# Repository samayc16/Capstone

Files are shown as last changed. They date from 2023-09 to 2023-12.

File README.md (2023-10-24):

# Code Documentation for Full STEAM Ahead
### Samay Chandna
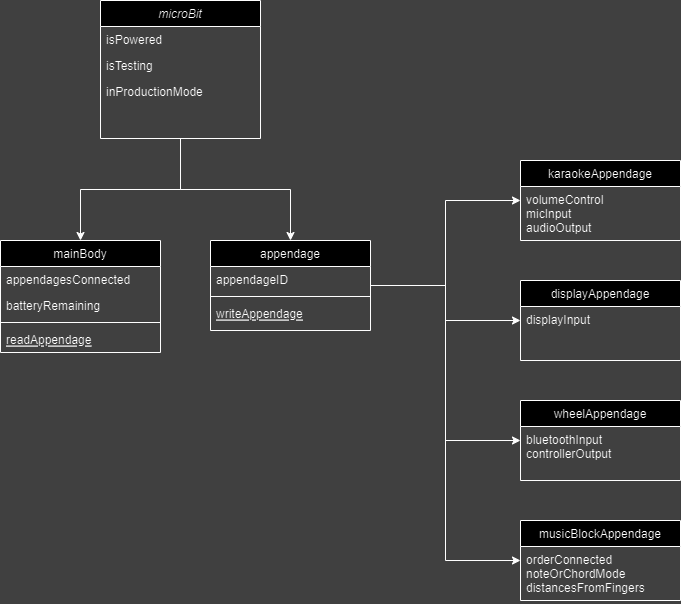
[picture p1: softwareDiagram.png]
OOP Software Diagram

#### Useful Links
* [micro:bit API for TS](https://makecode.microbit.org/reference)
* [micro:bit Pinout](https://makecode.microbit.org/device/pins)
* [micro:bit Progress with Simulator](https://makecode.microbit.org/_6Y6azqKkKF0U)

#### Progress Made so far
* 26/09/2023
  * [Have skeleton working in block code](https://makecode.microbit.org/_6Y6azqKkKF0U)
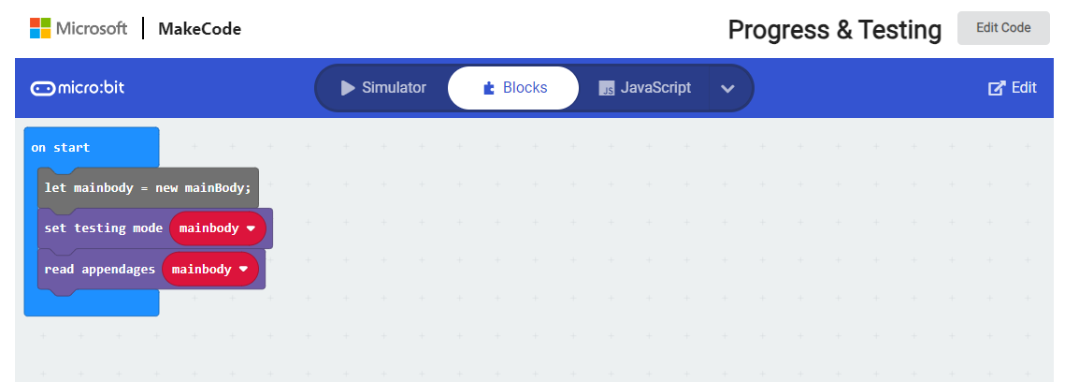
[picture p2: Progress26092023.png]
Today's Progress
  * 
* 28/09/2023
  * [Moved from naive implementation to I2C](https://makecode.microbit.org/S04872-52139-73553-07116)
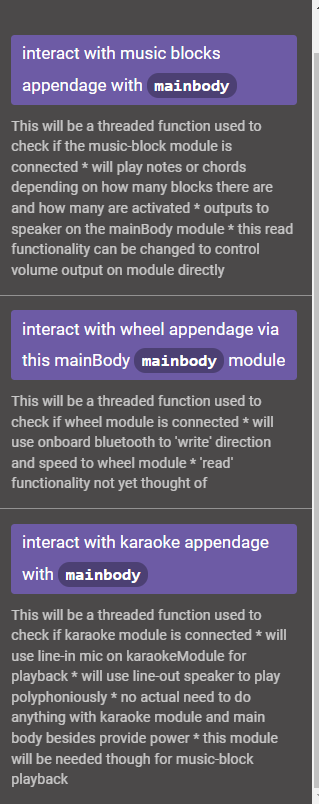
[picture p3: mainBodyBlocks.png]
Real block code with descriptions
  * 
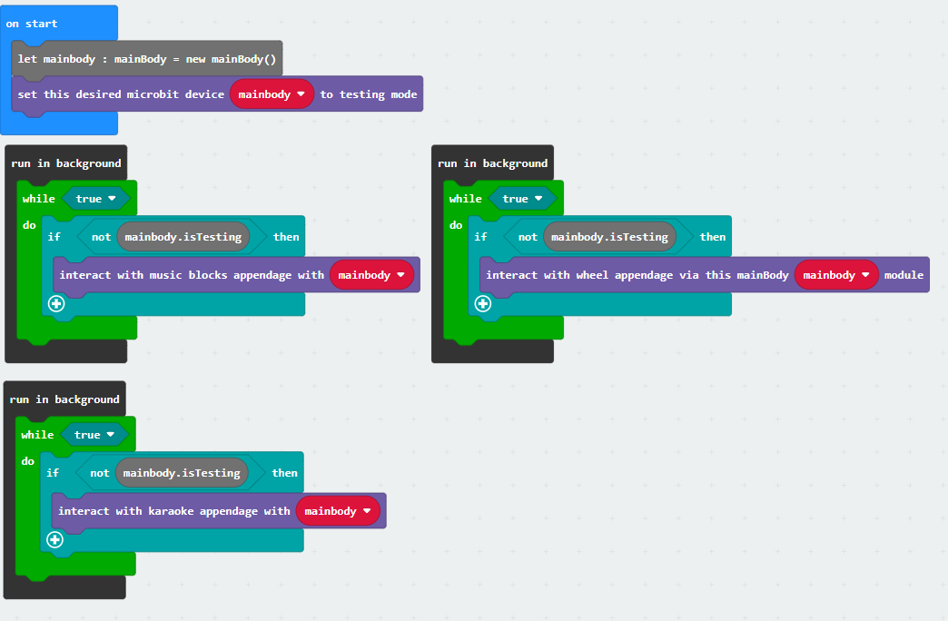
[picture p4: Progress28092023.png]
Today's Progress
  * 
* 24/10/2023
  * Little bit of absence due to midterms, break, and interviews
  * Great progress made, all the block code looks production-ready
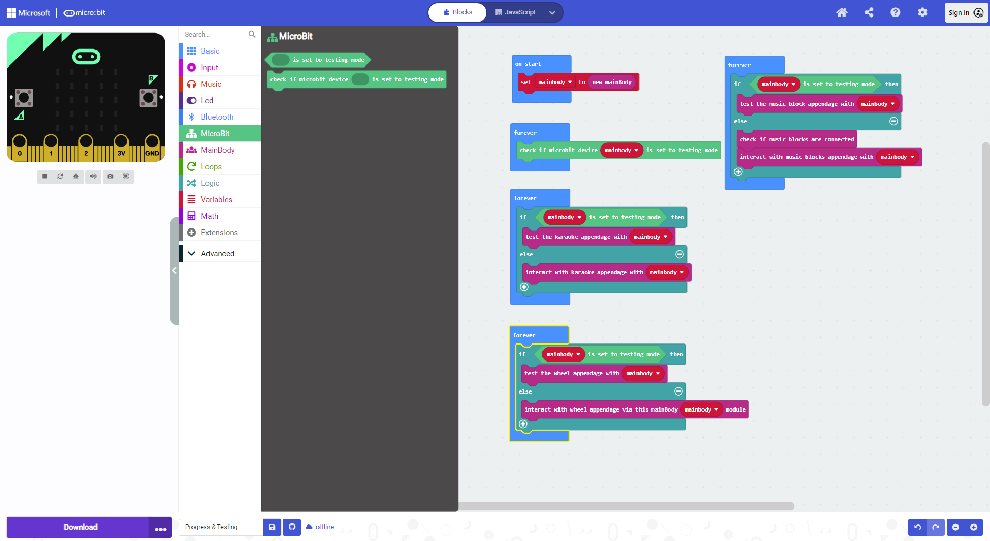
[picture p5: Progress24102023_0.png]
  * 
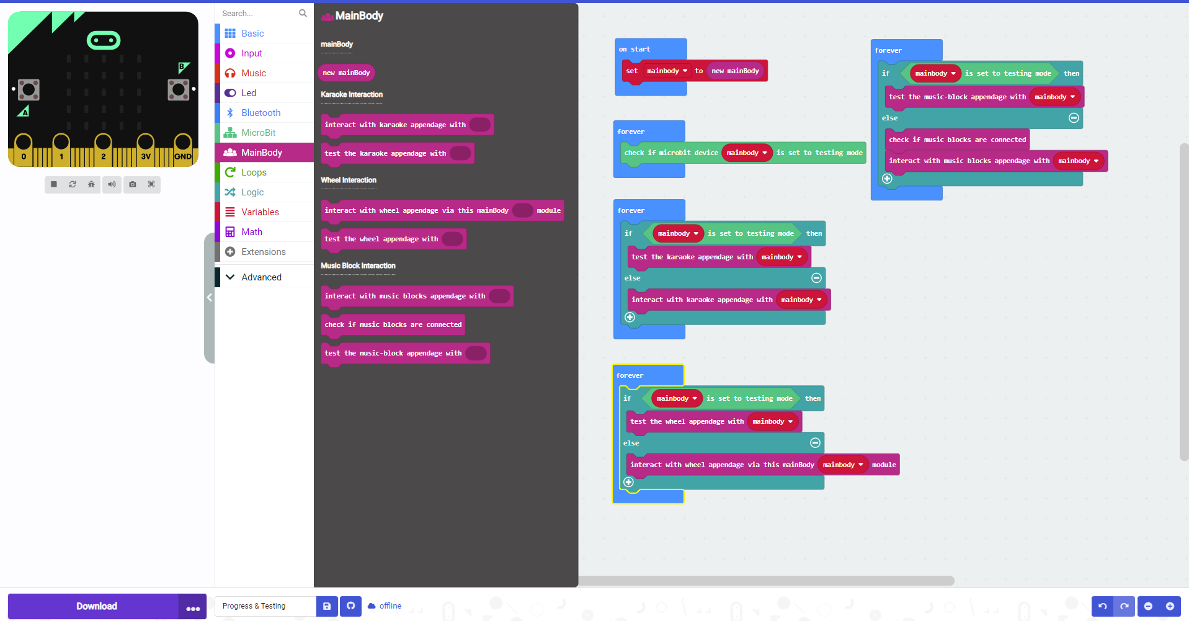
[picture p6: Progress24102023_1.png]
  * 
  * Deleted all deprecated python code
  * Deleted all TS files that are not being used
  * Got rid of custom.ts, made seperate modules for each (makes MUCH more sense)
  * Added PCB to github repo
  * Added my parts of CDR document and presentation

#### Helpful Notes
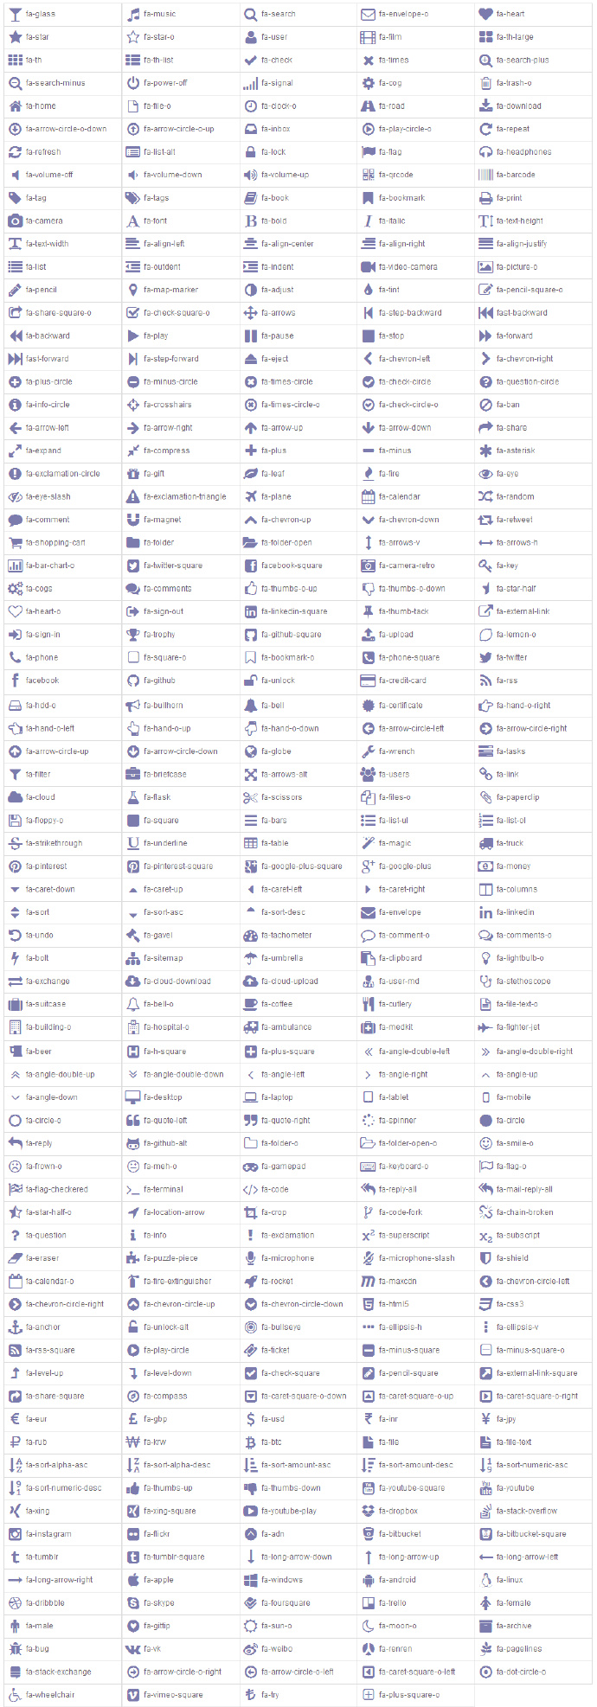
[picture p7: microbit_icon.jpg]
icons for microbit modules


*"\uf000", "id": "fa-glass"

*"\uf001", "id": "fa-music"

*"\uf002", "id": "fa-search"

*"\uf003", "id": "fa-envelope-o"

*"\uf004", "id": "fa-heart"

*"\uf005", "id": "fa-star"

*"\uf006", "id": "fa-star-o"

*"\uf007", "id": "fa-user"

*"\uf008", "id": "fa-film"

*"\uf009", "id": "fa-th-large"

*"\uf00a", "id": "fa-th"

*"\uf00b", "id": "fa-th-list"

*"\uf00c", "id": "fa-check"

*"\uf00d", "id": "fa-times"

*"\uf00e", "id": "fa-search-plus"

*"\uf010", "id": "fa-search-minus"

*"\uf011", "id": "fa-power-off"

*"\uf012", "id": "fa-signal"

*"\uf013", "id": "fa-cog"

*"\uf014", "id": "fa-trash-o"

*"\uf015", "id": "fa-home"

*"\uf016", "id": "fa-file-o"

*"\uf017", "id": "fa-clock-o"

*"\uf018", "id": "fa-road"

*"\uf019", "id": "fa-download"

*"\uf01a", "id": "fa-arrow-circle-o-down"

*"\uf01b", "id": "fa-arrow-circle-o-up"

*"\uf01c", "id": "fa-inbox"

*"\uf01d", "id": "fa-play-circle-o"

*"\uf01e", "id": "fa-repeat"

*"\uf021", "id": "fa-refresh"

*"\uf022", "id": "fa-list-alt"

*"\uf023", "id": "fa-lock"

*"\uf024", "id": "fa-flag"

*"\uf025", "id": "fa-headphones"

*"\uf026", "id": "fa-volume-off"

*"\uf027", "id": "fa-volume-down"

*"\uf028", "id": "fa-volume-up"

*"\uf029", "id": "fa-qrcode"

*"\uf02a", "id": "fa-barcode"

*"\uf02b", "id": "fa-tag"

*"\uf02c", "id": "fa-tags"

*"\uf02d", "id": "fa-book"

*"\uf02e", "id": "fa-bookmark"

*"\uf02f", "id": "fa-print"

*"\uf030", "id": "fa-camera"

*"\uf031", "id": "fa-font"

*"\uf032", "id": "fa-bold"

*"\uf033", "id": "fa-italic"

*"\uf034", "id": "fa-text-height"

*"\uf035", "id": "fa-text-width"

*"\uf036", "id": "fa-align-left"

*"\uf037", "id": "fa-align-center"

*"\uf038", "id": "fa-align-right"

*"\uf039", "id": "fa-align-justify"

*"\uf03a", "id": "fa-list"

*"\uf03b", "id": "fa-outdent"

*"\uf03c", "id": "fa-indent"

*"\uf03d", "id": "fa-video-camera"

*"\uf03e", "id": "fa-picture-o"

*"\uf040", "id": "fa-pencil"

*"\uf041", "id": "fa-map-marker"

*"\uf042", "id": "fa-adjust"

*"\uf043", "id": "fa-tint"

*"\uf044", "id": "fa-pencil-square-o"

*"\uf045", "id": "fa-share-square-o"

*"\uf046", "id": "fa-check-square-o"

*"\uf047", "id": "fa-arrows"

*"\uf048", "id": "fa-step-backward"

*"\uf049", "id": "fa-fast-backward"

*"\uf04a", "id": "fa-backward"

*"\uf04b", "id": "fa-play"

*"\uf04c", "id": "fa-pause"

*"\uf04d", "id": "fa-stop"

*"\uf04e", "id": "fa-forward"

*"\uf050", "id": "fa-fast-forward"

*"\uf051", "id": "fa-step-forward"

*"\uf052", "id": "fa-eject"

*"\uf053", "id": "fa-chevron-left"

*"\uf054", "id": "fa-chevron-right"

*"\uf055", "id": "fa-plus-circle"

*"\uf056", "id": "fa-minus-circle"

*"\uf057", "id": "fa-times-circle"

*"\uf058", "id": "fa-check-circle"

*"\uf059", "id": "fa-question-circle"

*"\uf05a", "id": "fa-info-circle"

*"\uf05b", "id": "fa-crosshairs"

*"\uf05c", "id": "fa-times-circle-o"

*"\uf05d", "id": "fa-check-circle-o"

*"\uf05e", "id": "fa-ban"

*"\uf060", "id": "fa-arrow-left"

*"\uf061", "id": "fa-arrow-right"

*"\uf062", "id": "fa-arrow-up"

*"\uf063", "id": "fa-arrow-down"

*"\uf064", "id": "fa-share"

*"\uf065", "id": "fa-expand"

*"\uf066", "id": "fa-compress"

*"\uf067", "id": "fa-plus"

*"\uf068", "id": "fa-minus"

*"\uf069", "id": "fa-asterisk"

*"\uf06a", "id": "fa-exclamation-circle"

*"\uf06b", "id": "fa-gift"

*"\uf06c", "id": "fa-leaf"

*"\uf06d", "id": "fa-fire"

*"\uf06e", "id": "fa-eye"

*"\uf070", "id": "fa-eye-slash"

*"\uf071", "id": "fa-exclamation-triangle"

*"\uf072", "id": "fa-plane"

*"\uf073", "id": "fa-calendar"

*"\uf074", "id": "fa-random"

*"\uf075", "id": "fa-comment"

*"\uf076", "id": "fa-magnet"

*"\uf077", "id": "fa-chevron-up"

*"\uf078", "id": "fa-chevron-down"

*"\uf079", "id": "fa-retweet"

*"\uf07a", "id": "fa-shopping-cart"

*"\uf07b", "id": "fa-folder"

*"\uf07c", "id": "fa-folder-open"

*"\uf07d", "id": "fa-arrows-v"

*"\uf07e", "id": "fa-arrows-h"

*"\uf080", "id": "fa-bar-chart-o"

*"\uf081", "id": "fa-twitter-square"

*"\uf082", "id": "fa-facebook-square"

*"\uf083", "id": "fa-camera-retro"

*"\uf084", "id": "fa-key"

*"\uf085", "id": "fa-cogs"

*"\uf086", "id": "fa-comments"

*"\uf087", "id": "fa-thumbs-o-up"

*"\uf088", "id": "fa-thumbs-o-down"

*"\uf089", "id": "fa-star-half"

*"\uf08a", "id": "fa-heart-o"

*"\uf08b", "id": "fa-sign-out"

*"\uf08c", "id": "fa-linkedin-square"

*"\uf08d", "id": "fa-thumb-tack"

*"\uf08e", "id": "fa-external-link"

*"\uf090", "id": "fa-sign-in"

*"\uf091", "id": "fa-trophy"

*"\uf092", "id": "fa-github-square"

*"\uf093", "id": "fa-upload"

*"\uf094", "id": "fa-lemon-o"

*"\uf095", "id": "fa-phone"

*"\uf096", "id": "fa-square-o"

*"\uf097", "id": "fa-bookmark-o"

*"\uf098", "id": "fa-phone-square"

*"\uf099", "id": "fa-twitter"

*"\uf09a", "id": "fa-facebook"

*"\uf09b", "id": "fa-github"

*"\uf09c", "id": "fa-unlock"

*"\uf09d", "id": "fa-credit-card"

*"\uf09e", "id": "fa-rss"

*"\uf0a0", "id": "fa-hdd-o"

*"\uf0a1", "id": "fa-bullhorn"

*"\uf0f3", "id": "fa-bell"

*"\uf0a3", "id": "fa-certificate"

*"\uf0a4", "id": "fa-hand-o-right"

*"\uf0a5", "id": "fa-hand-o-left"

*"\uf0a6", "id": "fa-hand-o-up"

*"\uf0a7", "id": "fa-hand-o-down"

*"\uf0a8", "id": "fa-arrow-circle-left"

*"\uf0a9", "id": "fa-arrow-circle-right"

*"\uf0aa", "id": "fa-arrow-circle-up"

*"\uf0ab", "id": "fa-arrow-circle-down"

*"\uf0ac", "id": "fa-globe"

*"\uf0ad", "id": "fa-wrench"

*"\uf0ae", "id": "fa-tasks"

*"\uf0b0", "id": "fa-filter"

*"\uf0b1", "id": "fa-briefcase"

*"\uf0b2", "id": "fa-arrows-alt"

*"\uf0c0", "id": "fa-users"

*"\uf0c1", "id": "fa-link"

*"\uf0c2", "id": "fa-cloud"

*"\uf0c3", "id": "fa-flask"

*"\uf0c4", "id": "fa-scissors"

*"\uf0c5", "id": "fa-files-o"

*"\uf0c6", "id": "fa-paperclip"

*"\uf0c7", "id": "fa-floppy-o"

*"\uf0c8", "id": "fa-square"

*"\uf0c9", "id": "fa-bars"

*"\uf0ca", "id": "fa-list-ul"

*"\uf0cb", "id": "fa-list-ol"

*"\uf0cc", "id": "fa-strikethrough"

*"\uf0cd", "id": "fa-underline"

*"\uf0ce", "id": "fa-table"

*"\uf0d0", "id": "fa-magic"

*"\uf0d1", "id": "fa-truck"

*"\uf0d2", "id": "fa-pinterest"

*"\uf0d3", "id": "fa-pinterest-square"

*"\uf0d4", "id": "fa-google-plus-square"

*"\uf0d5", "id": "fa-google-plus"

*"\uf0d6", "id": "fa-money"

*"\uf0d7", "id": "fa-caret-down"

*"\uf0d8", "id": "fa-caret-up"

*"\uf0d9", "id": "fa-caret-left"

*"\uf0da", "id": "fa-caret-right"

*"\uf0db", "id": "fa-columns"

*"\uf0dc", "id": "fa-sort"

*"\uf0dd", "id": "fa-sort-asc"

*"\uf0de", "id": "fa-sort-desc"

*"\uf0e0", "id": "fa-envelope"

*"\uf0e1", "id": "fa-linkedin"

*"\uf0e2", "id": "fa-undo"

*"\uf0e3", "id": "fa-gavel"

*"\uf0e4", "id": "fa-tachometer"

*"\uf0e5", "id": "fa-comment-o"

*"\uf0e6", "id": "fa-comments-o"

*"\uf0e7", "id": "fa-bolt"

*"\uf0e8", "id": "fa-sitemap"

*"\uf0e9", "id": "fa-umbrella"

*"\uf0ea", "id": "fa-clipboard"

*"\uf0eb", "id": "fa-lightbulb-o"

*"\uf0ec", "id": "fa-exchange"

*"\uf0ed", "id": "fa-cloud-download"

*"\uf0ee", "id": "fa-cloud-upload"

*"\uf0f0", "id": "fa-user-md"

*"\uf0f1", "id": "fa-stethoscope"

*"\uf0f2", "id": "fa-suitcase"

*"\uf0a2", "id": "fa-bell-o"

*"\uf0f4", "id": "fa-coffee"

*"\uf0f5", "id": "fa-cutlery"

*"\uf0f6", "id": "fa-file-text-o"

*"\uf0f7", "id": "fa-building-o"

*"\uf0f8", "id": "fa-hospital-o"

*"\uf0f9", "id": "fa-ambulance"

*"\uf0fa", "id": "fa-medkit"

*"\uf0fb", "id": "fa-fighter-jet"

*"\uf0fc", "id": "fa-beer"

*"\uf0fd", "id": "fa-h-square"

*"\uf0fe", "id": "fa-plus-square"

*"\uf100", "id": "fa-angle-double-left"

*"\uf101", "id": "fa-angle-double-right"

*"\uf102", "id": "fa-angle-double-up"

*"\uf103", "id": "fa-angle-double-down"

*"\uf104", "id": "fa-angle-left"

*"\uf105", "id": "fa-angle-right"

*"\uf106", "id": "fa-angle-up"

*"\uf107", "id": "fa-angle-down"

*"\uf108", "id": "fa-desktop"

*"\uf109", "id": "fa-laptop"

*"\uf10a", "id": "fa-tablet"

*"\uf10b", "id": "fa-mobile"

*"\uf10c", "id": "fa-circle-o"

*"\uf10d", "id": "fa-quote-left"

*"\uf10e", "id": "fa-quote-right"

*"\uf110", "id": "fa-spinner"

*"\uf111", "id": "fa-circle"

*"\uf112", "id": "fa-reply"

*"\uf113", "id": "fa-github-alt"

*"\uf114", "id": "fa-folder-o"

*"\uf115", "id": "fa-folder-open-o"

*"\uf118", "id": "fa-smile-o"

*"\uf119", "id": "fa-frown-o"

*"\uf11a", "id": "fa-meh-o"

*"\uf11b", "id": "fa-gamepad"

*"\uf11c", "id": "fa-keyboard-o"

*"\uf11d", "id": "fa-flag-o"

*"\uf11e", "id": "fa-flag-checkered"

*"\uf120", "id": "fa-terminal"

*"\uf121", "id": "fa-code"

*"\uf122", "id": "fa-reply-all"

*"\uf122", "id": "fa-mail-reply-all"

*"\uf123", "id": "fa-star-half-o"

*"\uf124", "id": "fa-location-arrow"

*"\uf125", "id": "fa-crop"

*"\uf126", "id": "fa-code-fork"

*"\uf127", "id": "fa-chain-broken"

*"\uf128", "id": "fa-question"

*"\uf129", "id": "fa-info"

*"\uf12a", "id": "fa-exclamation"

*"\uf12b", "id": "fa-superscript"

*"\uf12c", "id": "fa-subscript"

*"\uf12d", "id": "fa-eraser"

*"\uf12e", "id": "fa-puzzle-piece"

*"\uf130", "id": "fa-microphone"

*"\uf131", "id": "fa-microphone-slash"

*"\uf132", "id": "fa-shield"

*"\uf133", "id": "fa-calendar-o"

*"\uf134", "id": "fa-fire-extinguisher"

*"\uf135", "id": "fa-rocket"

*"\uf136", "id": "fa-maxcdn"

*"\uf137", "id": "fa-chevron-circle-left"

*"\uf138", "id": "fa-chevron-circle-right"

*"\uf139", "id": "fa-chevron-circle-up"

*"\uf13a", "id": "fa-chevron-circle-down"

*"\uf13b", "id": "fa-html5"

*"\uf13c", "id": "fa-css3"

*"\uf13d", "id": "fa-anchor"

*"\uf13e", "id": "fa-unlock-alt"

*"\uf140", "id": "fa-bullseye"

*"\uf141", "id": "fa-ellipsis-h"

*"\uf142", "id": "fa-ellipsis-v"

*"\uf143", "id": "fa-rss-square"

*"\uf144", "id": "fa-play-circle"

*"\uf145", "id": "fa-ticket"

*"\uf146", "id": "fa-minus-square"

*"\uf147", "id": "fa-minus-square-o"

*"\uf148", "id": "fa-level-up"

*"\uf149", "id": "fa-level-down"

*"\uf14a", "id": "fa-check-square"

*"\uf14b", "id": "fa-pencil-square"

*"\uf14c", "id": "fa-external-link-square"

*"\uf14d", "id": "fa-share-square"

*"\uf14e", "id": "fa-compass"

*"\uf150", "id": "fa-caret-square-o-down"

*"\uf151", "id": "fa-caret-square-o-up"

*"\uf152", "id": "fa-caret-square-o-right"

*"\uf153", "id": "fa-eur"

*"\uf154", "id": "fa-gbp"

*"\uf155", "id": "fa-usd"

*"\uf156", "id": "fa-inr"

*"\uf157", "id": "fa-jpy"

*"\uf158", "id": "fa-rub"

*"\uf159", "id": "fa-krw"

*"\uf15a", "id": "fa-btc"

*"\uf15b", "id": "fa-file"

*"\uf15c", "id": "fa-file-text"

*"\uf15d", "id": "fa-sort-alpha-asc"

*"\uf15e", "id": "fa-sort-alpha-desc"

*"\uf160", "id": "fa-sort-amount-asc"

*"\uf161", "id": "fa-sort-amount-desc"

*"\uf162", "id": "fa-sort-numeric-asc"

*"\uf163", "id": "fa-sort-numeric-desc"

*"\uf164", "id": "fa-thumbs-up"

*"\uf165", "id": "fa-thumbs-down"

*"\uf166", "id": "fa-youtube-square"

*"\uf167", "id": "fa-youtube"

*"\uf168", "id": "fa-xing"

*"\uf169", "id": "fa-xing-square"

*"\uf16a", "id": "fa-youtube-play"

*"\uf16b", "id": "fa-dropbox"

*"\uf16c", "id": "fa-stack-overflow"

*"\uf16d", "id": "fa-instagram"

*"\uf16e", "id": "fa-flickr"

*"\uf170", "id": "fa-adn"

*"\uf171", "id": "fa-bitbucket"

*"\uf172", "id": "fa-bitbucket-square"

*"\uf173", "id": "fa-tumblr"

*"\uf174", "id": "fa-tumblr-square"

*"\uf175", "id": "fa-long-arrow-down"

*"\uf176", "id": "fa-long-arrow-up"

*"\uf177", "id": "fa-long-arrow-left"

*"\uf178", "id": "fa-long-arrow-right"

*"\uf179", "id": "fa-apple"

*"\uf17a", "id": "fa-windows"

*"\uf17b", "id": "fa-android"

*"\uf17c", "id": "fa-linux"

*"\uf17d", "id": "fa-dribbble"

*"\uf17e", "id": "fa-skype"

*"\uf180", "id": "fa-foursquare"

*"\uf181", "id": "fa-trello"

*"\uf182", "id": "fa-female"

*"\uf183", "id": "fa-male"

*"\uf184", "id": "fa-gittip"

*"\uf185", "id": "fa-sun-o"

*"\uf186", "id": "fa-moon-o"

*"\uf187", "id": "fa-archive"

*"\uf188", "id": "fa-bug"

*"\uf189", "id": "fa-vk"

*"\uf18a", "id": "fa-weibo"

*"\uf18b", "id": "fa-renren"

*"\uf18c", "id": "fa-pagelines"

*"\uf18d", "id": "fa-stack-exchange"

*"\uf18e", "id": "fa-arrow-circle-o-right"

*"\uf190", "id": "fa-arrow-circle-o-left"

*"\uf191", "id": "fa-caret-square-o-left"

*"\uf192", "id": "fa-dot-circle-o"

*"\uf193", "id": "fa-wheelchair"

*"\uf194", "id": "fa-vimeo-square"

*"\uf195", "id": "fa-try"

*"\uf196", "id": "fa-plus-square-o")

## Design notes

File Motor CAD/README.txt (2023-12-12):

**NOTES:**

The Servo Assembly and BLDC Assembly are imported from an open-source project called Dragon R1, hosted on Printables by @rambros.

Link: https://www.printables.com/model/240045-dragon-r1-open-source-rc-car
 
This work is licensed under a
Creative Commons (4.0 International License)
Attribution
License: https://creativecommons.org/licenses/by/4.0/

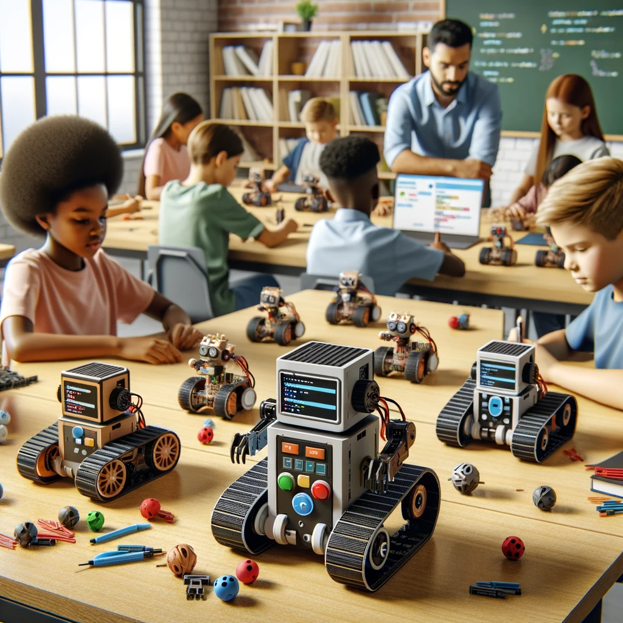
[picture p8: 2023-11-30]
theHope.png

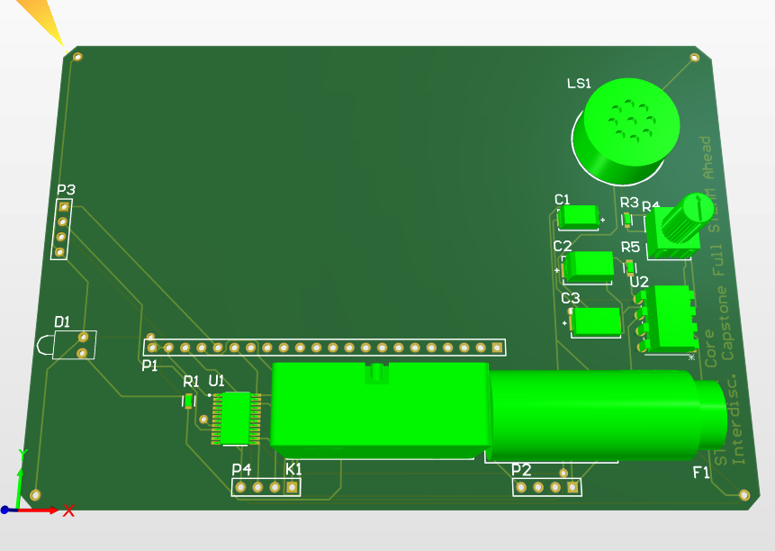
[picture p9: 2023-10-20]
PCB/core/pcbdraft1-front.png

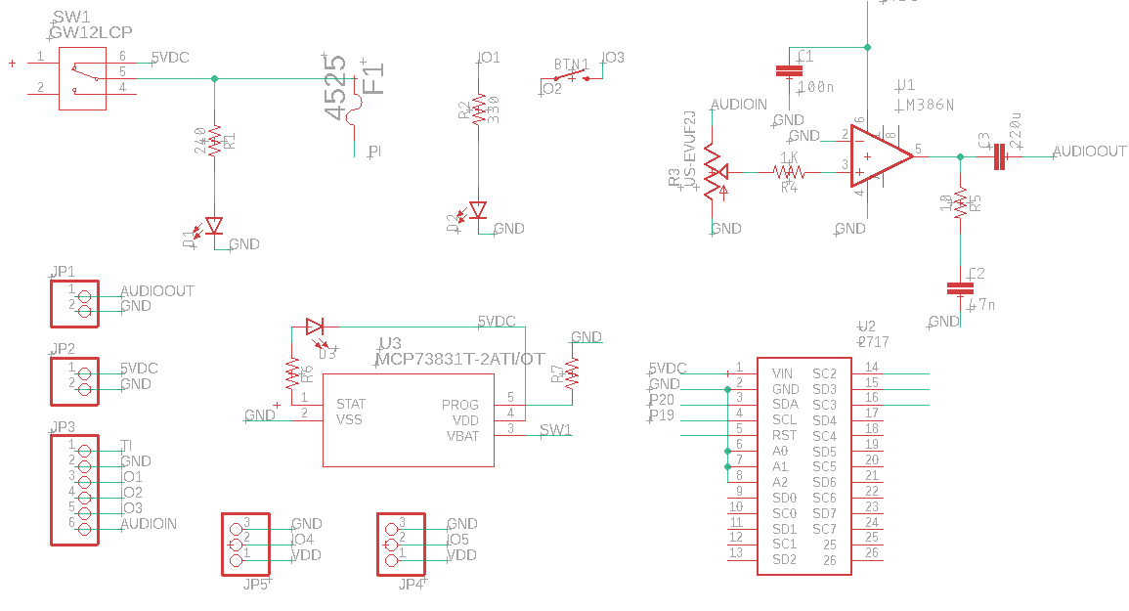
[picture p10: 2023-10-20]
PCB/eagle-drafts/pcb-v1.png

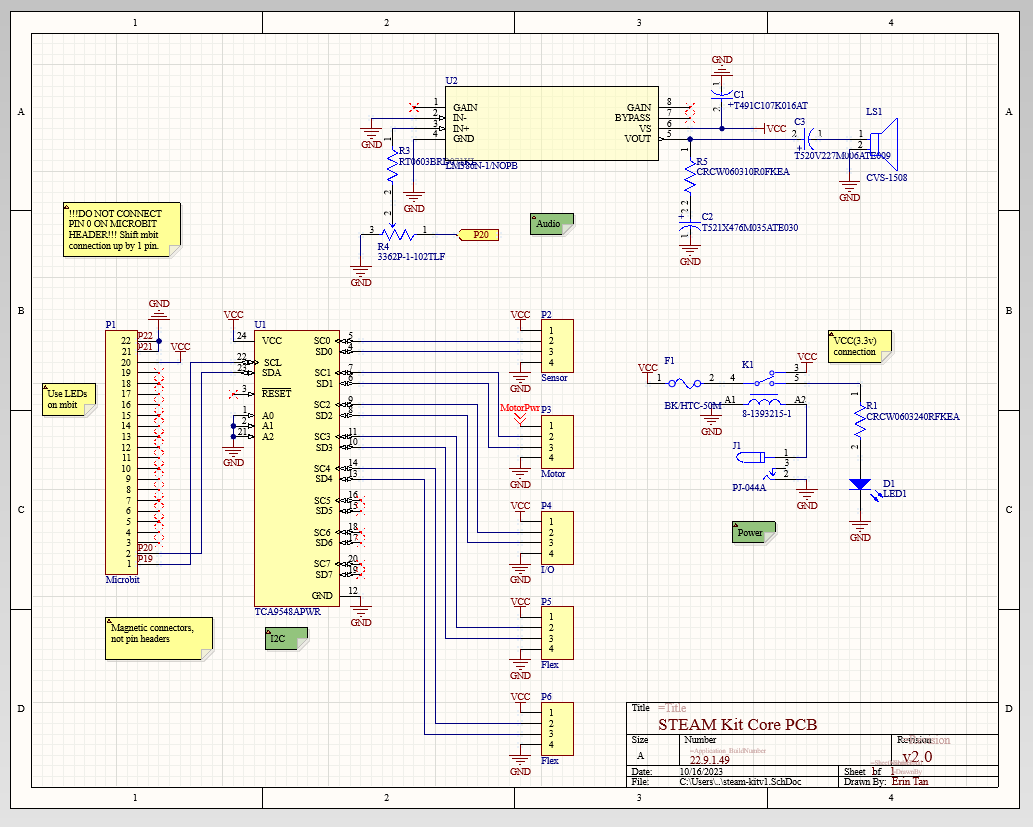
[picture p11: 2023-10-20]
PCB/core/core-sch-5out.png

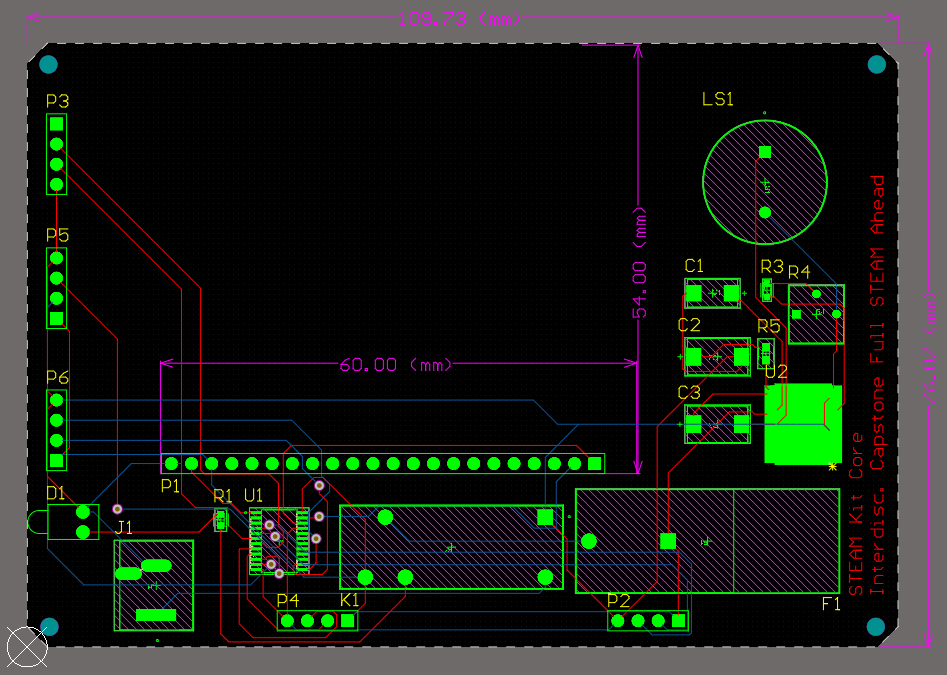
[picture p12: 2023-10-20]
PCB/core/core-routing-final-5out.png

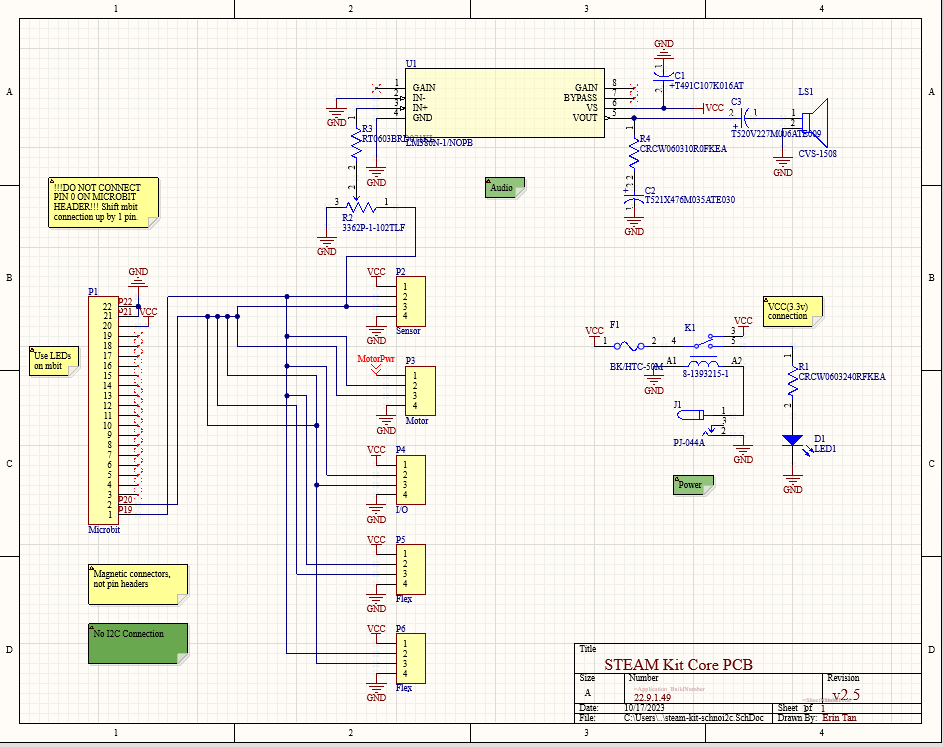
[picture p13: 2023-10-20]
PCB/core/noi2c.png

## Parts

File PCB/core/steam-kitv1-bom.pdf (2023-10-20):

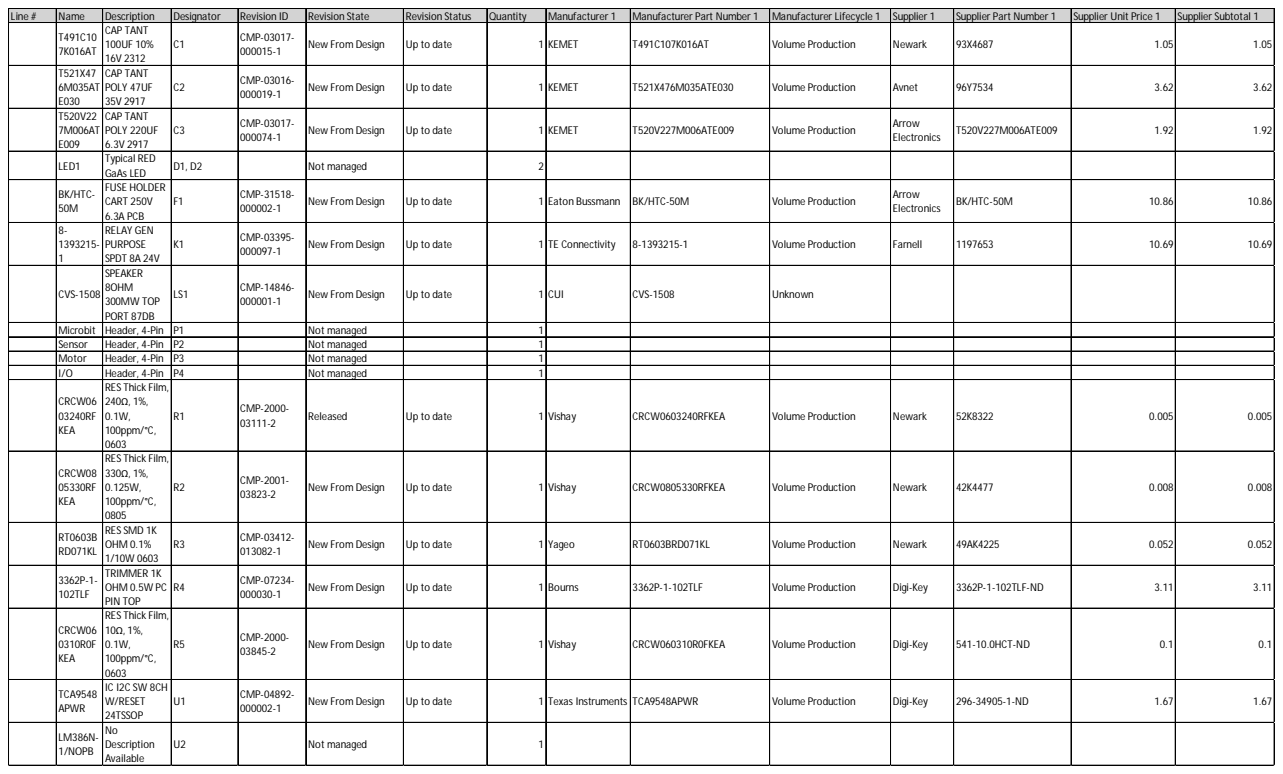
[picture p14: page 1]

Line # | Name | Description | Designator | Revision ID | Revision State | Revision Status | Quantity | Manufacturer 1 | Manufacturer Part Number 1 | Manufacturer Lifecycle 1 | Supplier 1 | Supplier Part Number 1 | Supplier Unit Price 1 | Supplier Subtotal 1

T491C10 7K016AT | CAP TANT 100UF 10% 16V 2312 | C1 | CMP-03017-000015-1 | New From Design | Up to date | 1 | KEMET | T491C107K016AT | Volume Production | Newark | 93X4687 | 1.05 | 1.05

T521X47 6M035AT E030 | CAP TANT POLY 47UF 35V 2917 | C2 | CMP-03016-000019-1 | New From Design | Up to date | 1 | KEMET | T521X476M035ATE030 | Volume Production | Avnet | 96Y7534 | 3.62 | 3.62

T520V22 7M006AT E009 | CAP TANT POLY 220UF 6.3V 2917 | C3 | CMP-03017-000074-1 | New From Design | Up to date | 1 | KEMET | T520V227M006ATE009 | Volume Production | Arrow Electronics | T520V227M006ATE009 | 1.92 | 1.92

LED1 | Typical RED GaAs LED | D1, D2 | | Not managed | | 2

BK/HTC-50M | FUSE HOLDER CART 250V 6.3A PCB | F1 | CMP-31518-000002-1 | New From Design | Up to date | 1 | Eaton Bussmann | BK/HTC-50M | Volume Production | Arrow Electronics | BK/HTC-50M | 10.86 | 10.86

8-1393215-1 | RELAY GEN PURPOSE SPDT 8A 24V | K1 | CMP-03395-000097-1 | New From Design | Up to date | 1 | TE Connectivity | 8-1393215-1 | Volume Production | Farnell | 1197653 | 10.69 | 10.69

CVS-1508 | SPEAKER 8OHM 300MW TOP PORT 87DB | LS1 | CMP-14846-000001-1 | New From Design | Up to date | 1 | CUI | CVS-1508 | Unknown

Microbit | Header, 4-Pin | P1 | | Not managed | | 1
Sensor | Header, 4-Pin | P2 | | Not managed | | 1
Motor | Header, 4-Pin | P3 | | Not managed | | 1
I/O | Header, 4-Pin | P4 | | Not managed | | 1
CRCW06 03240RF KEA | RES Thick Film, 240Ω, 1%, 0.1W, 100ppm/°C, 0603 | R1 | CMP-2000-03111-2 | Released | Up to date | 1 | Vishay | CRCW0603240RFKEA | Volume Production | Newark | 52K8322 | 0.005 | 0.005

CRCW08 05330RF KEA | RES Thick Film, 330Ω, 1%, 0.125W, 100ppm/°C, 0805 | R2 | CMP-2001-03823-2 | New From Design | Up to date | 1 | Vishay | CRCW0805330RFKEA | Volume Production | Newark | 42K4477 | 0.008 | 0.008

RT0603B RD071KL | RES SMD 1K OHM 0.1% 1/10W 0603 | R3 | CMP-03412-013082-1 | New From Design | Up to date | 1 | Yageo | RT0603BRD071KL | Volume Production | Newark | 49AK4225 | 0.052 | 0.052

3362P-1-102TLF | TRIMMER 1K OHM 0.5W PC PIN TOP | R4 | CMP-07234-000030-1 | New From Design | Up to date | 1 | Bourns | 3362P-1-102TLF | Volume Production | Digi-Key | 3362P-1-102TLF-ND | 3.11 | 3.11

CRCW06 0310R0F KEA | RES Thick Film, 10Ω, 1%, 0.1W, 100ppm/°C, 0603 | R5 | CMP-2000-03845-2 | New From Design | Up to date | 1 | Vishay | CRCW060310R0FKEA | Volume Production | Digi-Key | 541-10.0HCT-ND | 0.1 | 0.1

TCA9548 APWR | IC I2C SW 8CH W/RESET 24TSSOP | U1 | CMP-04892-000002-1 | New From Design | Up to date | 1 | Texas Instruments | TCA9548APWR | Volume Production | Digi-Key | 296-34905-1-ND | 1.67 | 1.67

LM386N-1/NOPB | No Description Available | U2 | | Not managed | | 1

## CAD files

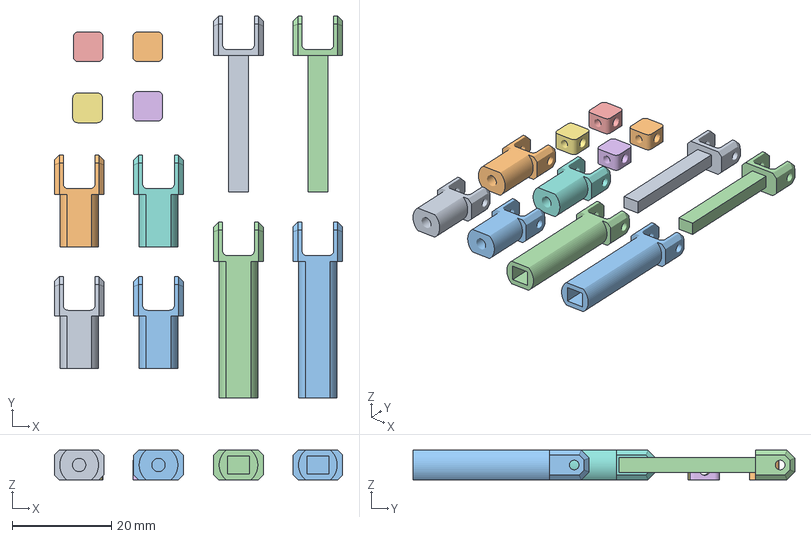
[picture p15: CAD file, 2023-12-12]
Motor CAD/STL/Rear chassis - Axle shaft/Real Axle - Full.3mf
58.1 x 77.0 x 6.00 mm
u joint telescopic shaft (X2).stl x 2
center (X4).stl x 4
u joint shaft (X4).stl x 4
u joint telescopic coupler (X2).stl x 2

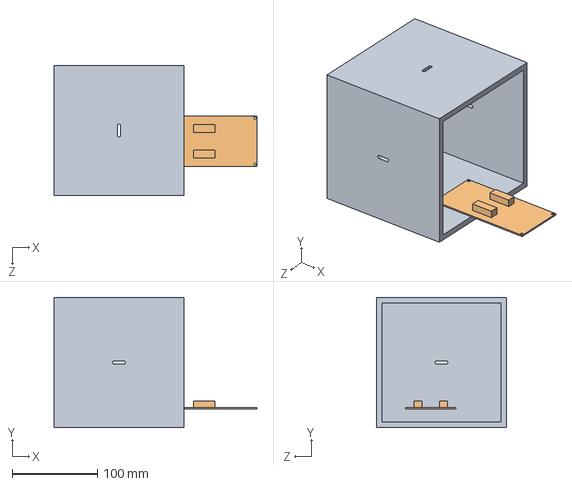
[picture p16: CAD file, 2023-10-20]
CAD/CubeAssembly.SLDASM
237.9 x 152.4 x 152.4 mm
3DPrintFabrication
TIMicrocontrollerEssentialDimensions

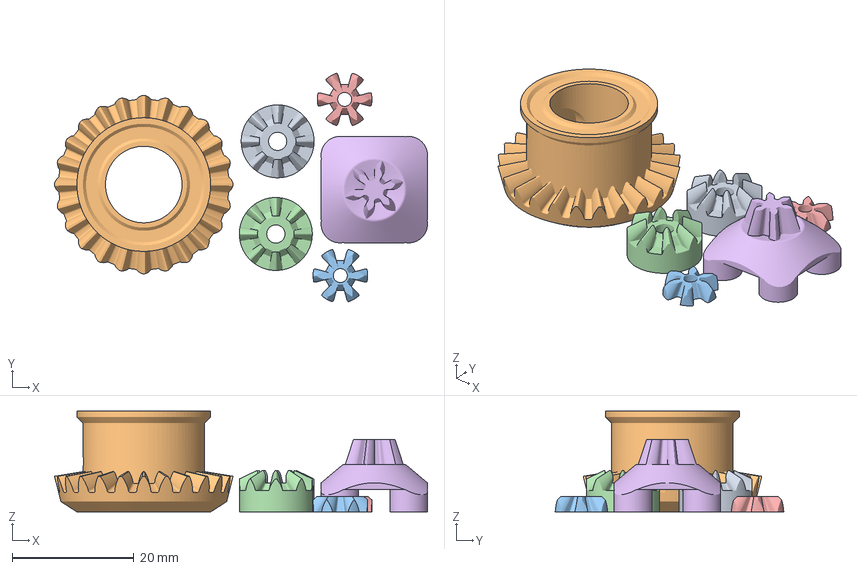
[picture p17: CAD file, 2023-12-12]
Motor CAD/STL/Rear chassis - Differential/Differential-full.3mf
61.4 x 37.6 x 16.6 mm
Differential-full.3mf
Differential-full.3mf(2)
Differential-full.3mf(3)
Differential-full.3mf(4)
Differential-full.3mf(5)
Pinion Gear.stl

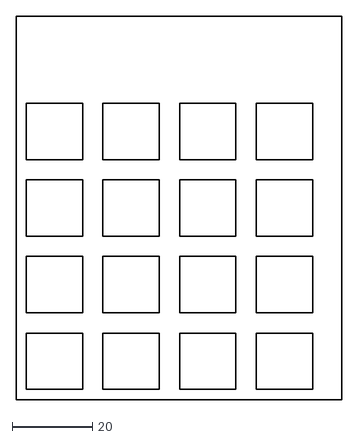
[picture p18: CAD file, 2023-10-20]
ButtonsModule/keysCadCase.dxf
81.0 x 95.2

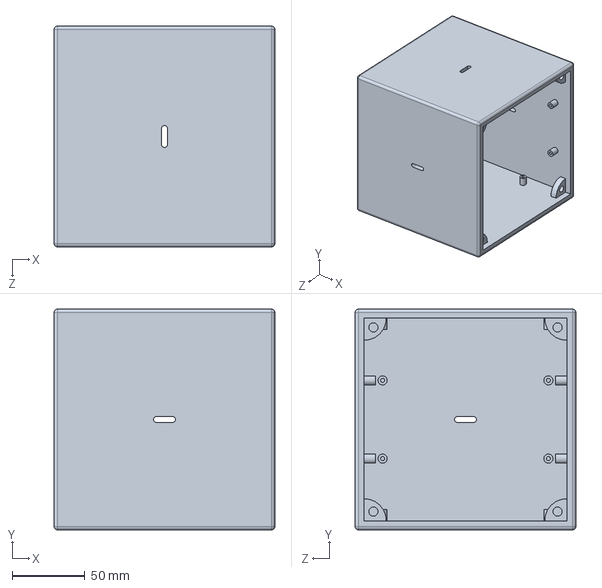
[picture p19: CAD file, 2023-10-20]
CAD/3DPrintFabrication.SLDPRT
152.4 x 152.4 x 152.4 mm

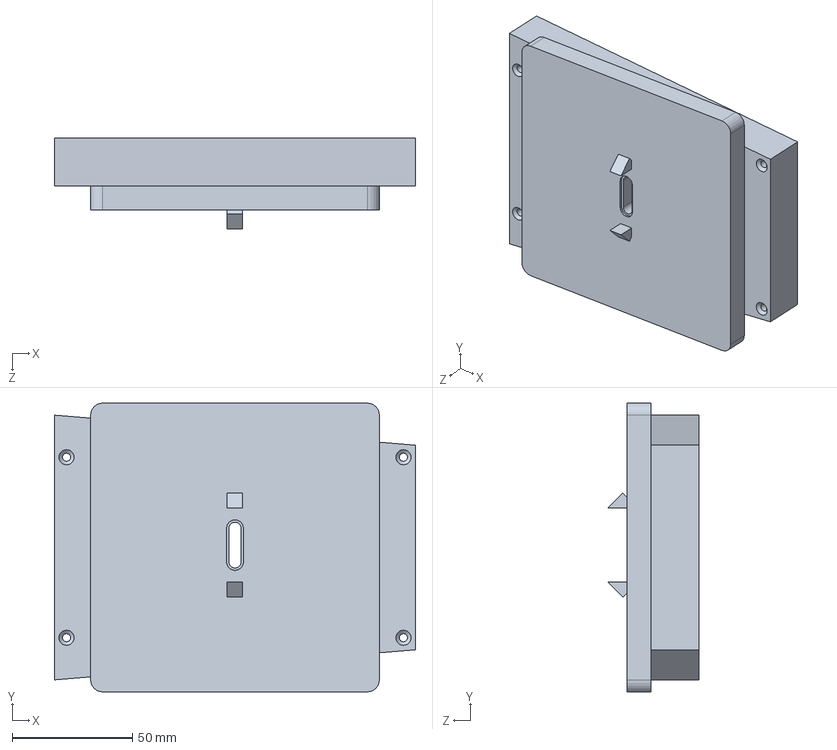
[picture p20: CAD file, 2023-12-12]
Motor CAD/Motor Module V3 Top.SLDPRT
150.0 x 120.0 x 37.8 mm

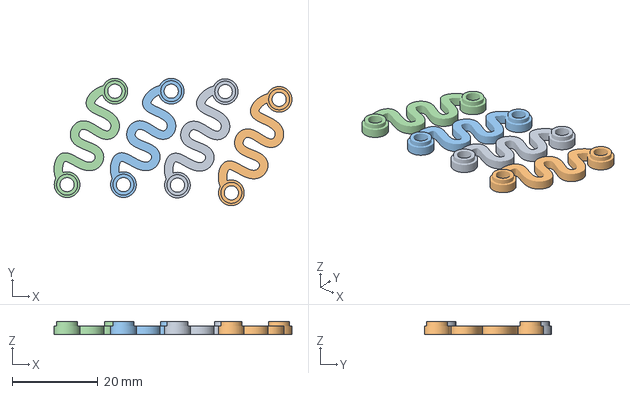
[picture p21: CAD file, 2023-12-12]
Motor CAD/STL/Front chassis - Frame/Front Springs.3mf
55.5 x 29.7 x 3.00 mm
spring tension front.stl x 4

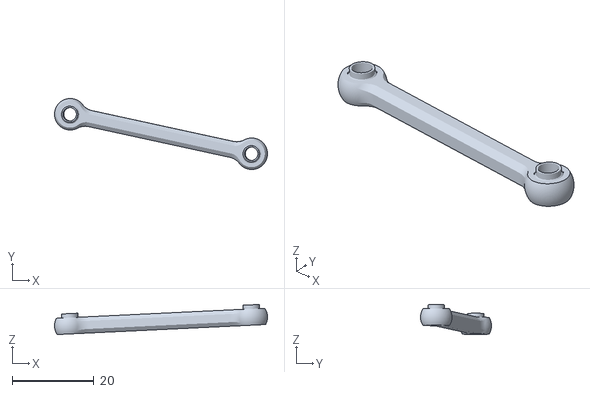
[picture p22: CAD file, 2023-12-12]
Motor CAD/STL/Front chassis - Steering/Tie Rod (X2).stl
52.3 x 17.4 x 7.39

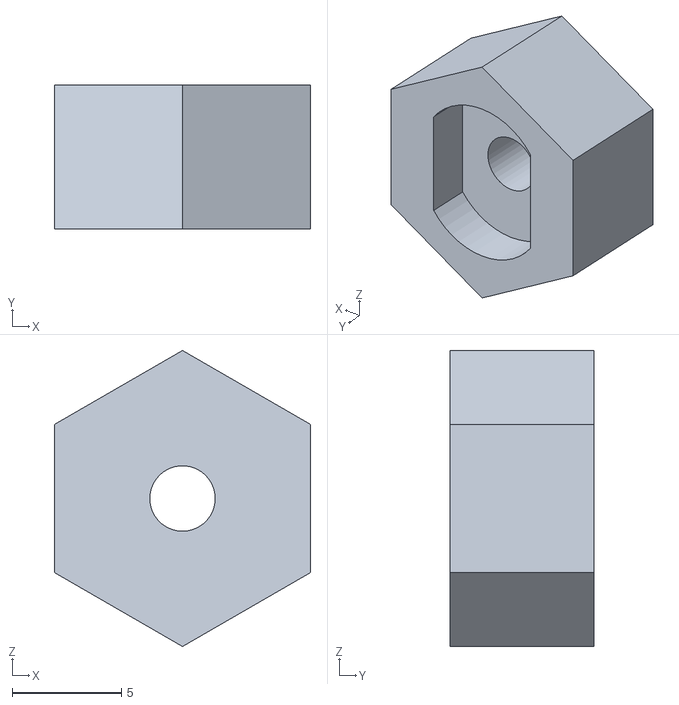
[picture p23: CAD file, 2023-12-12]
Motor CAD/STL/Housing/Wheels Converter Attachment V3 (x4).STL
11.8 x 6.60 x 13.6

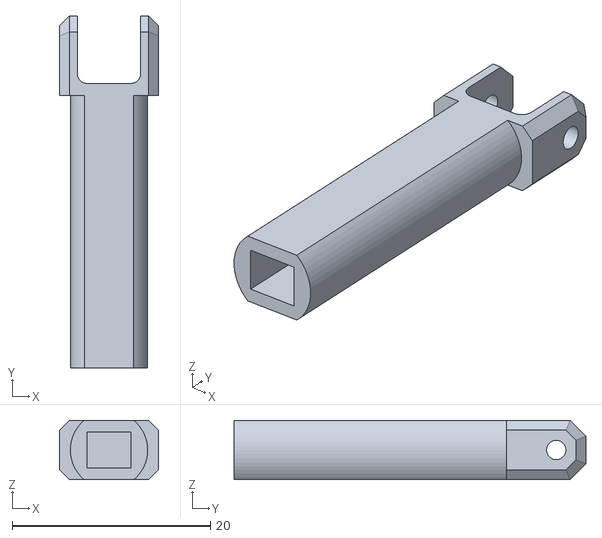
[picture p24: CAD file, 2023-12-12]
Motor CAD/STL/Rear chassis - Axle shaft/U Joint Telescopic Coupler (X2).stl
10.0 x 35.5 x 6.00

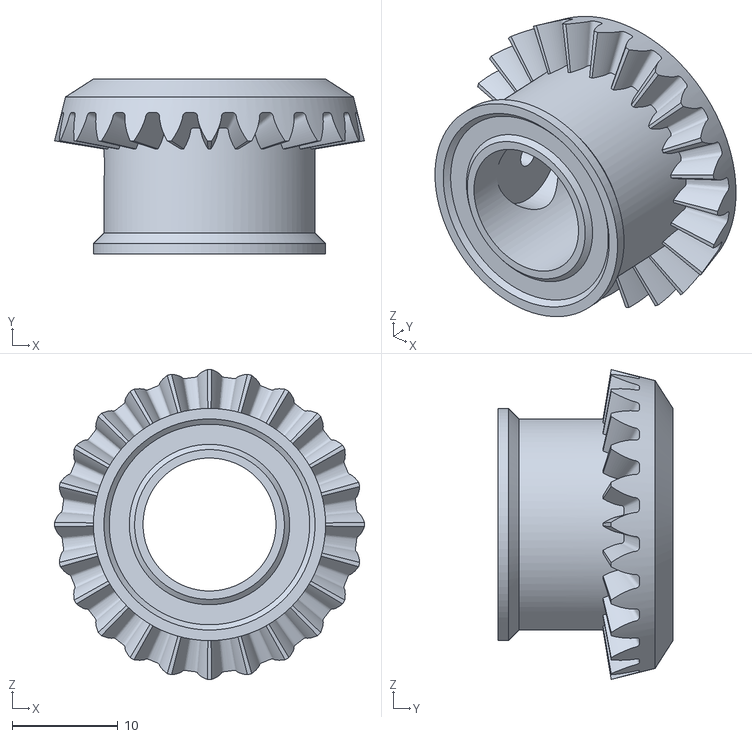
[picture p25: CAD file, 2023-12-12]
Motor CAD/STL/Rear chassis - Differential/Ring Gear.stl
29.4 x 16.6 x 29.4

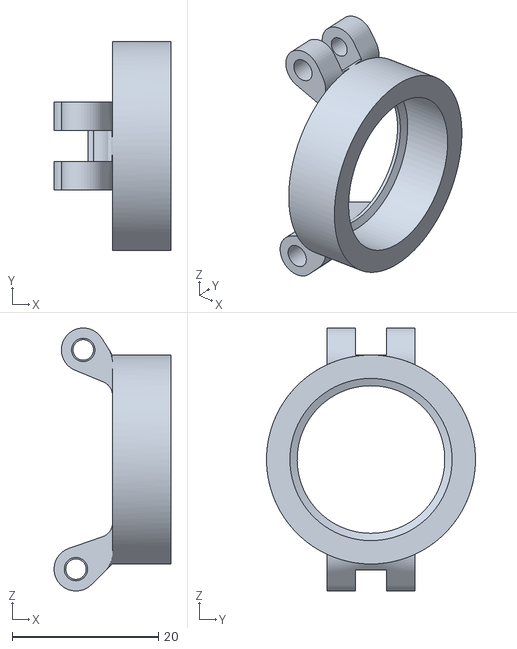
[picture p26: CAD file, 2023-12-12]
Motor CAD/STL/Rear chassis - Frame/Knuckle Rear Right.stl
16.0 x 28.6 x 36.0

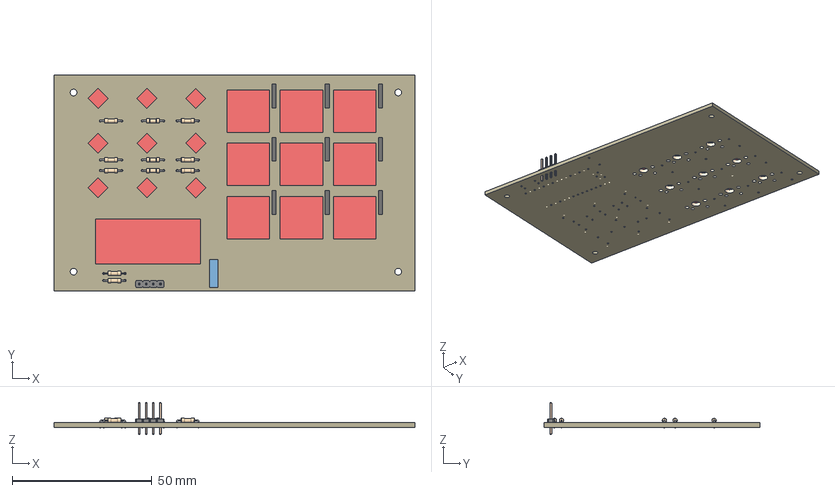
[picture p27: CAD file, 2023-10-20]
PCB/IO_module/capstoneIO.step
129.2 x 77.5 x 11.5 mm
Board
DO-1N4148 x 9
LED5MM x 9
10k x 11
CHERRY-MX x 9
6130xx11121_PIN x 4
NANO
.1 uF

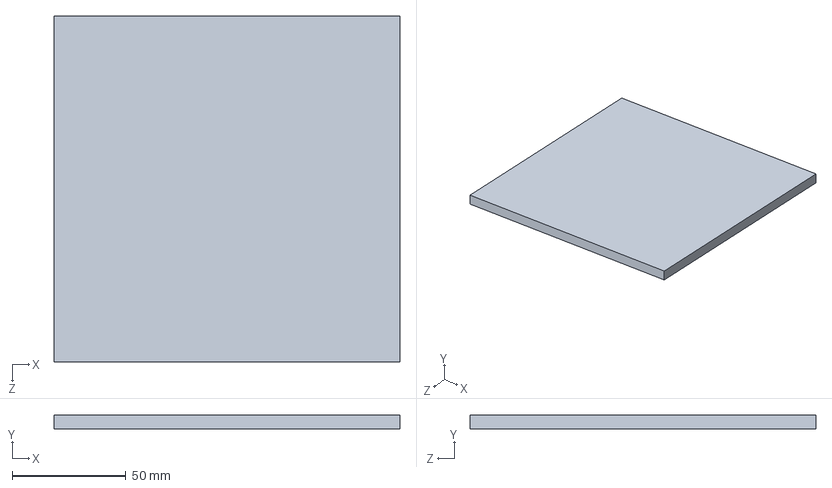
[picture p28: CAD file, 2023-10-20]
CAD/LaserCutInProgress.SLDPRT
152.4 x 6.35 x 152.4 mm

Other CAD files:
Motor CAD/Motor Module V3 Bottom.SLDPRT
Motor CAD/STL/Front chassis - Frame/Wishbone Front Lower Left.stl
Motor CAD/STL/Front chassis - Steering/Steering Parts.3mf
Motor CAD/STL/Housing/MotorModuleV3Top.STL
CAD/3DPrintFabrication.STL
CAD/3DPrintFabricationLatches.SLDPRT
CAD/3DPrintFabricationPlate.SLDPRT
CAD/3DPrintFabricationPlate.STL
CAD/TIMicrocontrollerEssentialDimensions.SLDPRT
Motor CAD/STL/Front chassis - Frame/Frame Front Bottom.stl
Motor CAD/STL/Front chassis - Frame/Frame Front Top.stl
Motor CAD/STL/Front chassis - Frame/Front Frame and Knuckles.3mf
Motor CAD/STL/Front chassis - Frame/Front Wishbones.3mf
Motor CAD/STL/Front chassis - Frame/Front spring.stl
Motor CAD/STL/Front chassis - Frame/Knuckle Front Left.stl
Motor CAD/STL/Front chassis - Frame/Knuckle Front Right.stl
Motor CAD/STL/Front chassis - Frame/Wishbone Front Lower Right.stl
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

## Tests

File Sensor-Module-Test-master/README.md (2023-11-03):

> Open this page at [https://akialter.github.io/sensor-module-test/](https://akialter.github.io/sensor-module-test/)

## Use as Extension

This repository can be added as an **extension** in MakeCode.

* open [https://makecode.microbit.org/](https://makecode.microbit.org/)
* click on **New Project**
* click on **Extensions** under the gearwheel menu
* search for **https://github.com/akialter/sensor-module-test** and import

## Edit this project

To edit this repository in MakeCode.

* open [https://makecode.microbit.org/](https://makecode.microbit.org/)
* click on **Import** then click on **Import URL**
* paste **https://github.com/akialter/sensor-module-test** and click import

#### Metadata (used for search, rendering)

* for PXT/microbit
<script src="https://makecode.com/gh-pages-embed.js"></script><script>makeCodeRender("{{ site.makecode.home_url }}", "{{ site.github.owner_name }}/{{ site.github.repository_name }}");</script>

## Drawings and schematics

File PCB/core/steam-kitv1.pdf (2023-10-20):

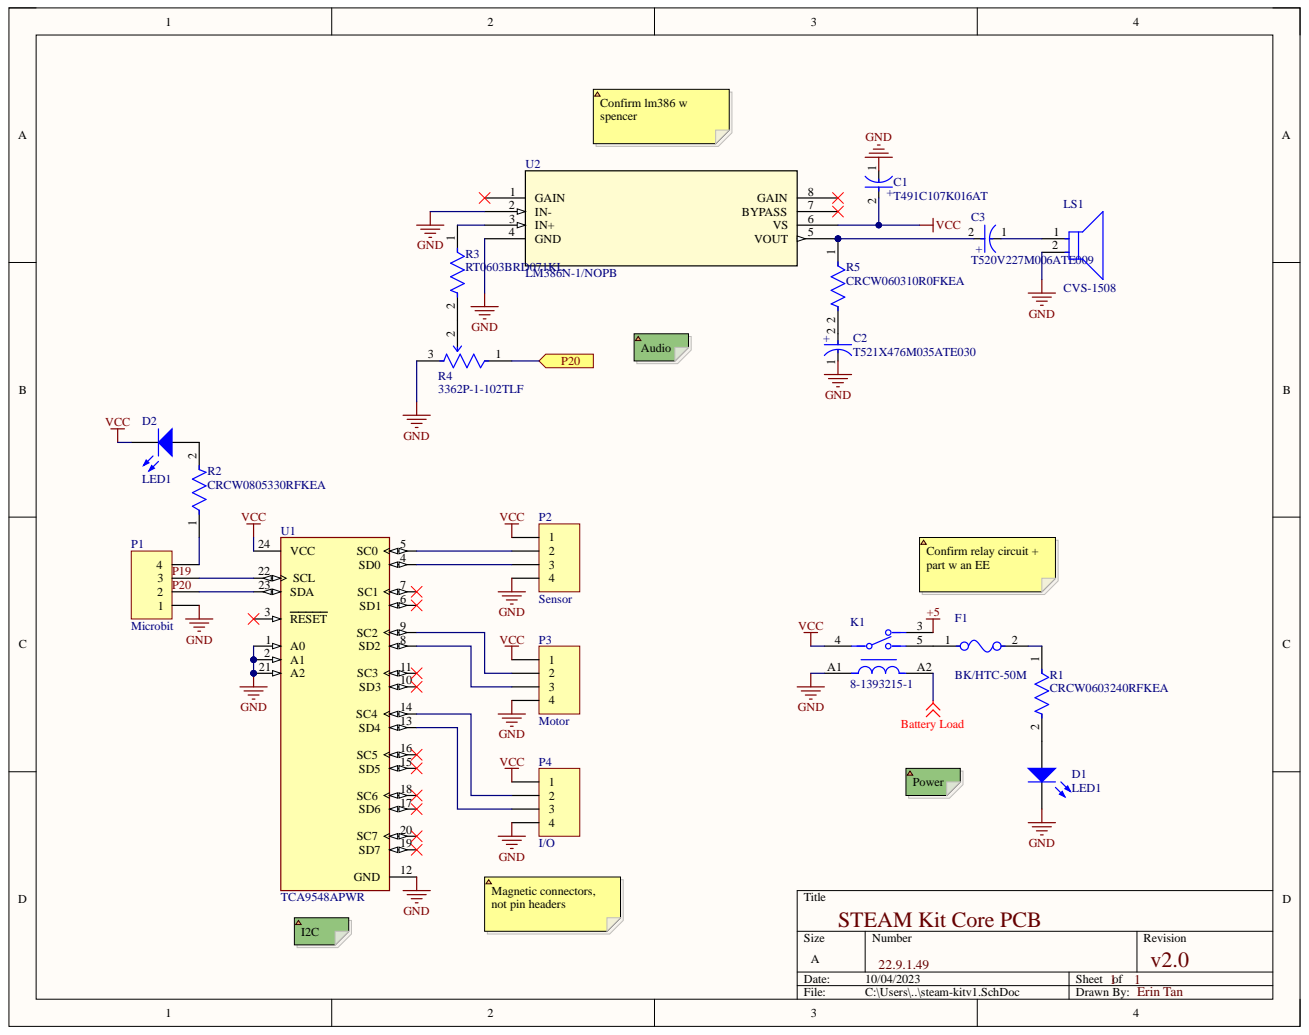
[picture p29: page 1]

VCC VCC VCC GND GND GND

STEAM Kit Core PCB

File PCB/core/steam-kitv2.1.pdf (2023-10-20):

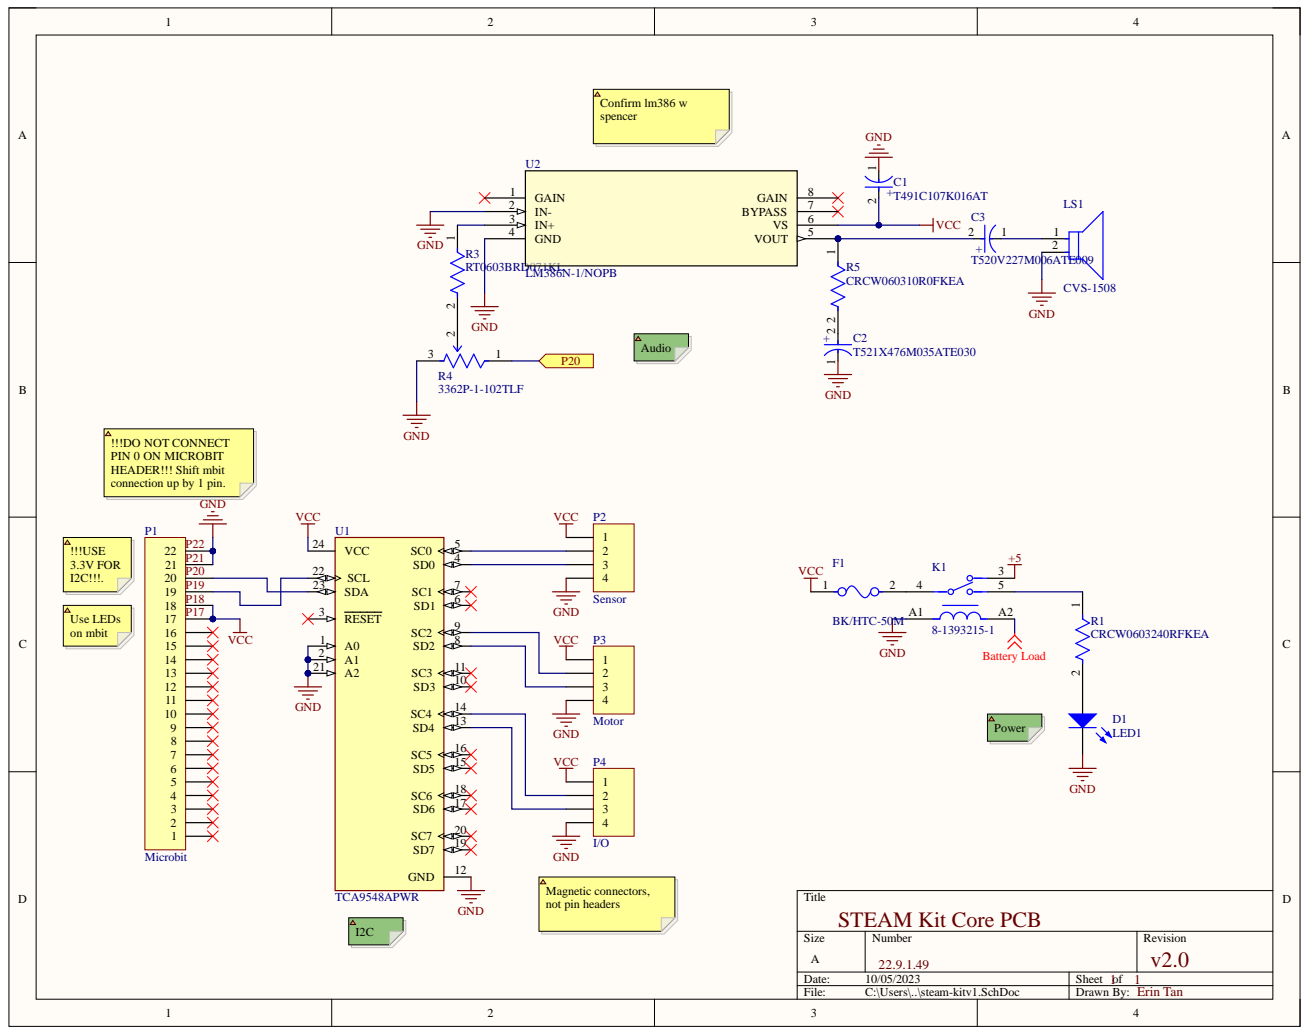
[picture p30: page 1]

VCC VCC VCC GND GND GND

STEAM Kit Core PCB

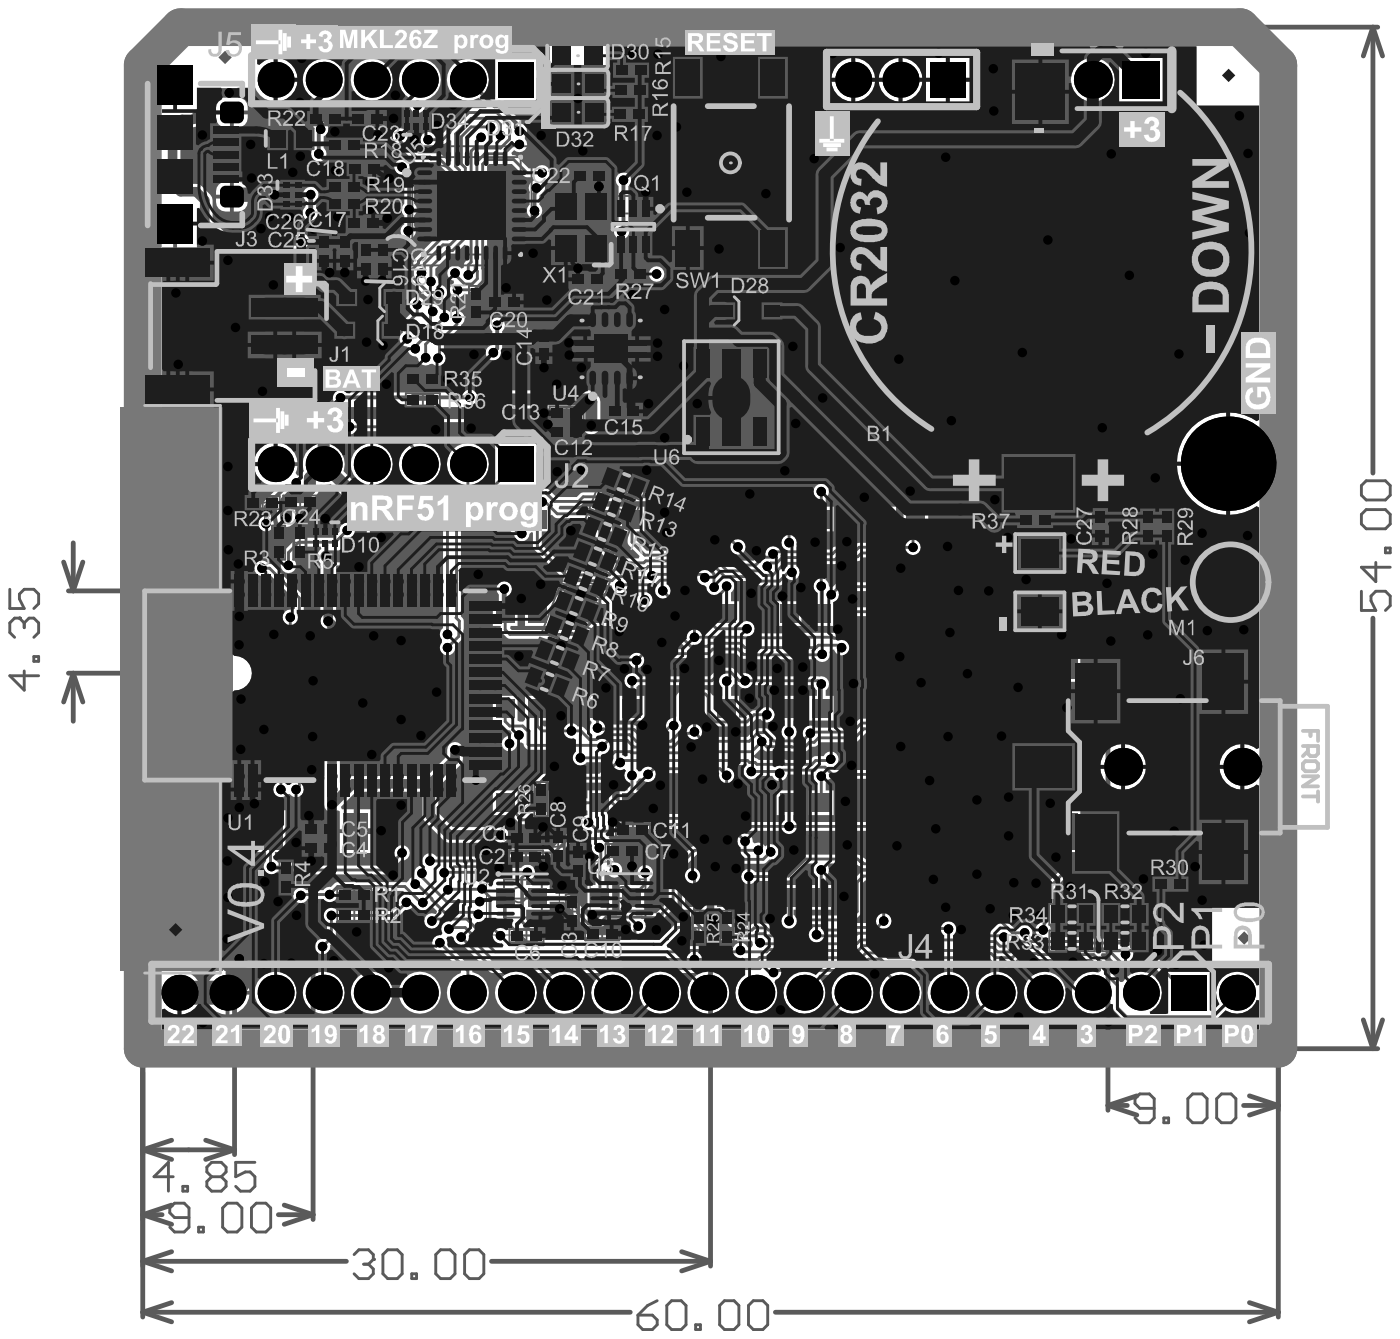
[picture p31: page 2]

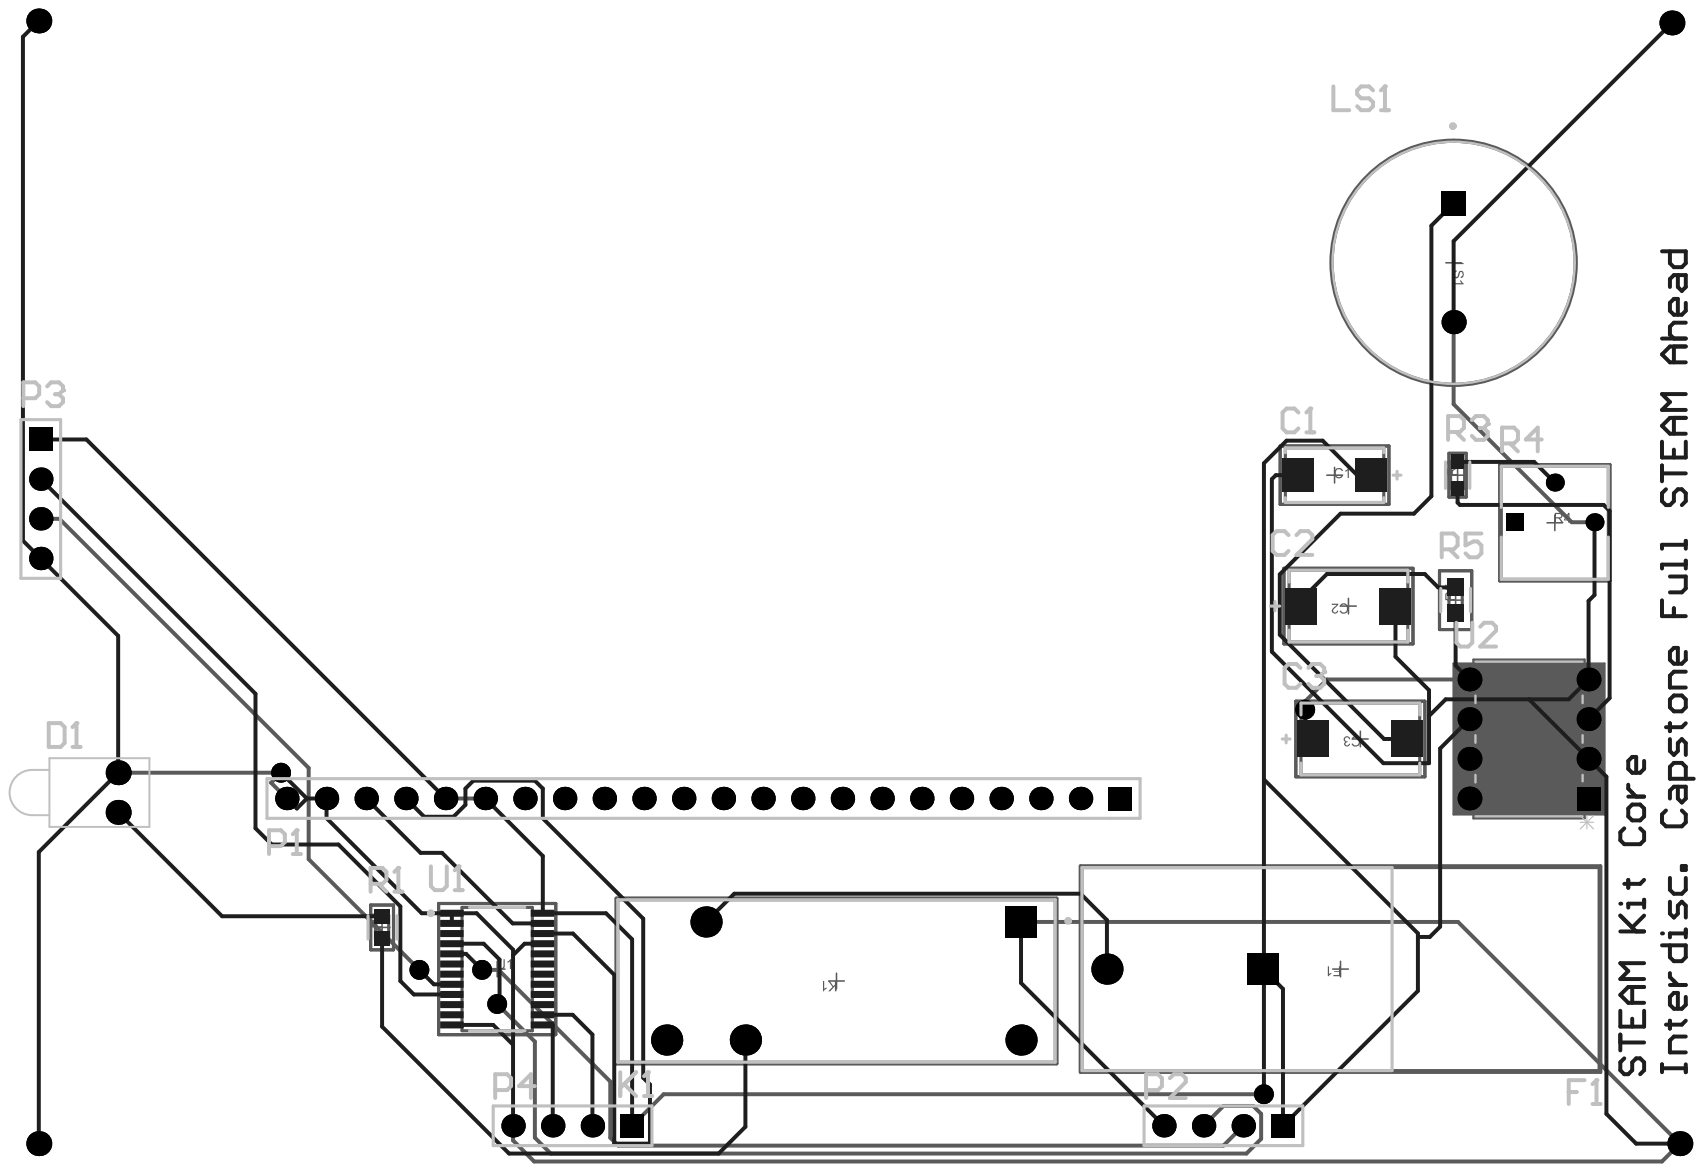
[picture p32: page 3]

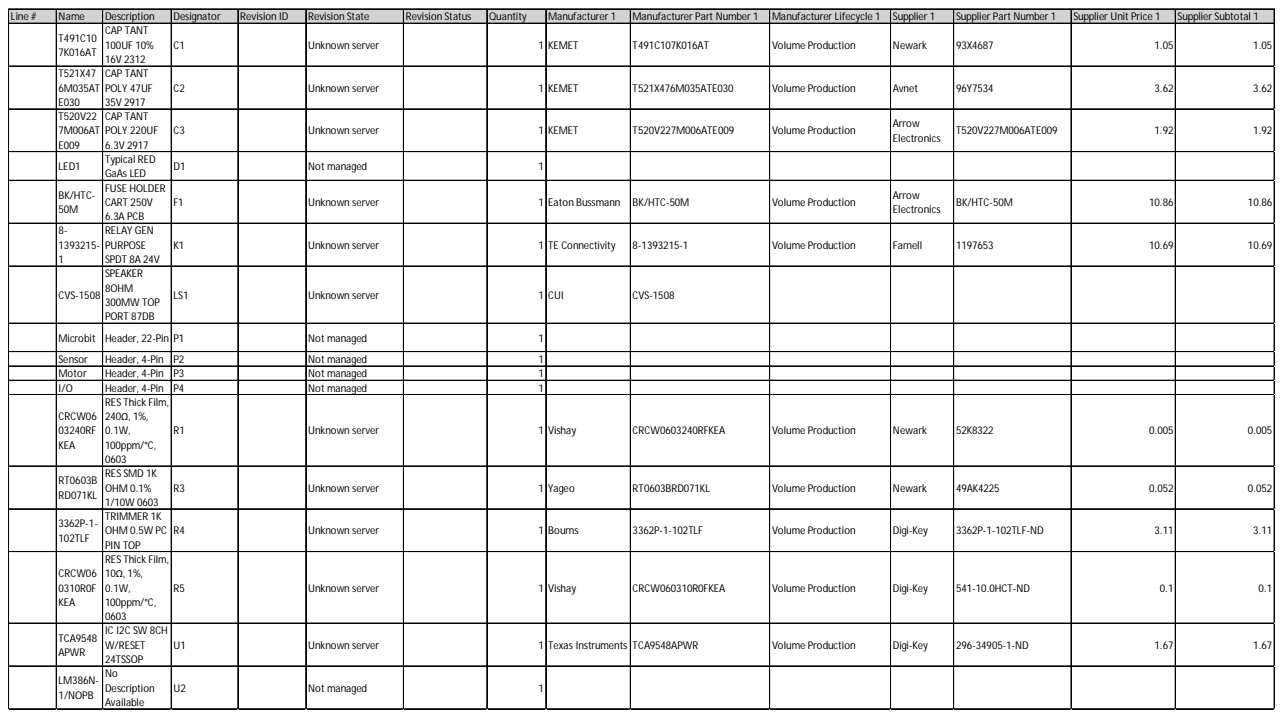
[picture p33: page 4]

Line # | Name | Description | Designator | Revision ID | Revision State | Revision Status | Quantity | Manufacturer 1 | Manufacturer Part Number 1 | Manufacturer Lifecycle 1 | Supplier 1 | Supplier Part Number 1 | Supplier Unit Price 1 | Supplier Subtotal 1

T491C10 7K016AT | CAP TANT 100UF 10% 16V 2312 | C1 | | Unknown server | | 1 | KEMET | T491C107K016AT | Volume Production | Newark | 93X4687 | 1.05 | 1.05

T521X47 6M035AT E030 | CAP TANT POLY 47UF 35V 2917 | C2 | | Unknown server | | 1 | KEMET | T521X476M035ATE030 | Volume Production | Avnet | 96Y7534 | 3.62 | 3.62

T520V22 7M006AT E009 | CAP TANT POLY 220UF 6.3V 2917 | C3 | | Unknown server | | 1 | KEMET | T520V227M006ATE009 | Volume Production | Arrow Electronics | T520V227M006ATE009 | 1.92 | 1.92

LED1 | Typical RED GaAs LED | D1 | | Not managed | | 1

BK/HTC-50M | FUSE HOLDER CART 250V 6.3A PCB | F1 | | Unknown server | | 1 | Eaton Bussmann | BK/HTC-50M | Volume Production | Arrow Electronics | BK/HTC-50M | 10.86 | 10.86

8-1393215-1 | RELAY GEN PURPOSE SPDT 8A 24V | K1 | | Unknown server | | 1 | TE Connectivity | 8-1393215-1 | Volume Production | Farnell | 1197653 | 10.69 | 10.69

CVS-1508 | SPEAKER 8OHM 300MW TOP PORT 87DB | LS1 | | Unknown server | | 1 | CUI | CVS-1508

Microbit | Header, 22-Pin | P1 | | Not managed | | 1

Sensor | Header, 4-Pin | P2 | | Not managed | | 1
Motor | Header, 4-Pin | P3 | | Not managed | | 1
I/O | Header, 4-Pin | P4 | | Not managed | | 1
CRCW06 03240RF KEA | RES Thick Film, 240Ω, 1%, 0.1W, 100ppm/°C, 0603 | R1 | | Unknown server | | 1 | Vishay | CRCW0603240RFKEA | Volume Production | Newark | 52K8322 | 0.005 | 0.005

RT0603B RD071KL | RES SMD 1K OHM 0.1% 1/10W 0603 | R3 | | Unknown server | | 1 | Yageo | RT0603BRD071KL | Volume Production | Newark | 49AK4225 | 0.052 | 0.052

3362P-1-102TLF | TRIMMER 1K OHM 0.5W PC PIN TOP | R4 | | Unknown server | | 1 | Bourns | 3362P-1-102TLF | Volume Production | Digi-Key | 3362P-1-102TLF-ND | 3.11 | 3.11

CRCW06 0310R0F KEA | RES Thick Film, 10Ω, 1%, 0.1W, 100ppm/°C, 0603 | R5 | | Unknown server | | 1 | Vishay | CRCW060310R0FKEA | Volume Production | Digi-Key | 541-10.0HCT-ND | 0.1 | 0.1

TCA9548 APWR | IC I2C SW 8CH W/RESET 24TSSOP | U1 | | Unknown server | | 1 | Texas Instruments | TCA9548APWR | Volume Production | Digi-Key | 296-34905-1-ND | 1.67 | 1.67

LM386N-1/NOPB | No Description Available | U2 | | Not managed | | 1

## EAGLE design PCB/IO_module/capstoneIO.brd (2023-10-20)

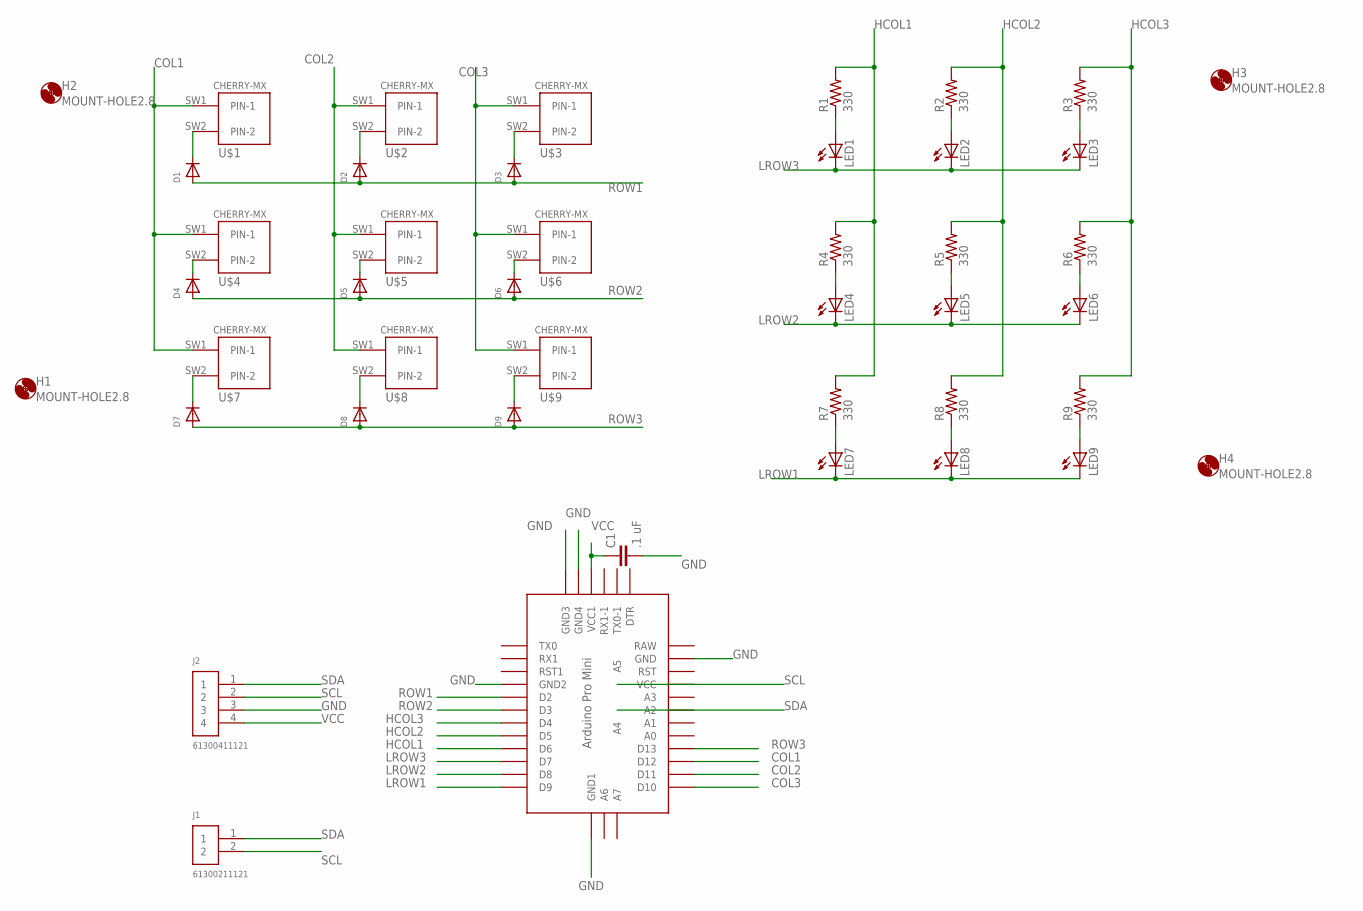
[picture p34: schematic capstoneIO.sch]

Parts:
C1: .1 uF; C075-032X103-AARON
D1, D2, D3, D4, D5, D6, D7, D8, D9: DIODEDO-1N4148; DO-1N4148
H1, H2, H3, H4: MOUNT-HOLE2.8; 2,8
J1: 61300211121
J2: 61300411121
LED1, LED2, LED3, LED4, LED5, LED6, LED7, LED8, LED9: LED5MM
R1, R2, R3, R4, R5, R6, R7, R8, R9: 330; 0204/7
U$1, U$2, U$3, U$4, U$5, U$6, U$7, U$8, U$9: CHERRY-MX
U$10: ABK-PRO-MINI

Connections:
COL1: U$1.SW1 (PIN-1), U$4.SW1 (PIN-1), U$7.SW1 (PIN-1), U$10.D12
COL2: U$2.SW1 (PIN-1), U$5.SW1 (PIN-1), U$8.SW1 (PIN-1), U$10.D11
COL3: U$3.SW1 (PIN-1), U$6.SW1 (PIN-1), U$9.SW1 (PIN-1), U$10.D10
GND: C1.2, J2.3, U$10.GND, U$10.GND1 (GND2), U$10.GND2 (GND3), U$10.GND3 (GND4), U$10.GND4 (GND1)
HCOL1: R1.2, R4.2, R7.2, U$10.D6
HCOL2: R2.2, R5.2, R8.2, U$10.D5
HCOL3: R3.2, R6.2, R9.2, U$10.D4
LROW1: LED7.K (C), LED8.K (C), LED9.K (C), U$10.D9
LROW2: LED4.K (C), LED5.K (C), LED6.K (C), U$10.D8
LROW3: LED1.K (C), LED2.K (C), LED3.K (C), U$10.D7
unnamed: LED1.A, R1.1
unnamed: LED2.A, R2.1
unnamed: LED3.A, R3.1
unnamed: D1.C, U$1.SW2 (PIN-2)
unnamed: LED4.A, R4.1
unnamed: D3.C, U$3.SW2 (PIN-2)
unnamed: D2.C, U$2.SW2 (PIN-2)
unnamed: D4.C, U$4.SW2 (PIN-2)
unnamed: D5.C, U$5.SW2 (PIN-2)
unnamed: D6.C, U$6.SW2 (PIN-2)
unnamed: LED5.A, R5.1
unnamed: D7.C, U$7.SW2 (PIN-2)
unnamed: D8.C, U$8.SW2 (PIN-2)
unnamed: D9.C, U$9.SW2 (PIN-2)
unnamed: LED6.A, R6.1
unnamed: LED7.A, R7.1
unnamed: LED8.A, R8.1
unnamed: LED9.A, R9.1
ROW1: D1.A, D2.A, D3.A, U$10.D2
ROW2: D4.A, D5.A, D6.A, U$10.D3
ROW3: D7.A, D8.A, D9.A, U$10.D13
SCL: J1.2, J2.2, U$10.A5
SDA: J1.1, J2.1, U$10.A4
VCC: C1.1, J2.4, U$10.VCC1

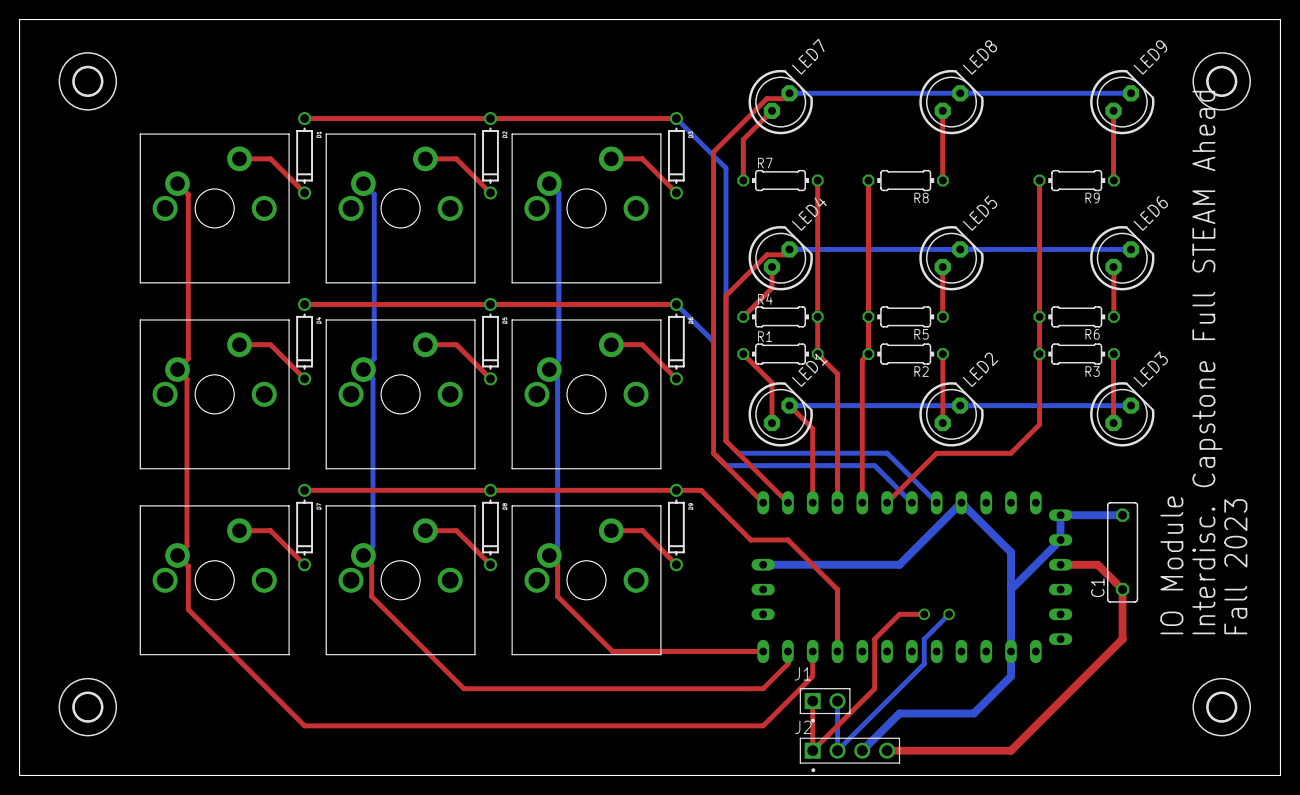
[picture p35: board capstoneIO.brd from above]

Board: 2 copper layers, 129.2 x 77.5 mm, 44 parts (0 on the bottom side), 34 nets.

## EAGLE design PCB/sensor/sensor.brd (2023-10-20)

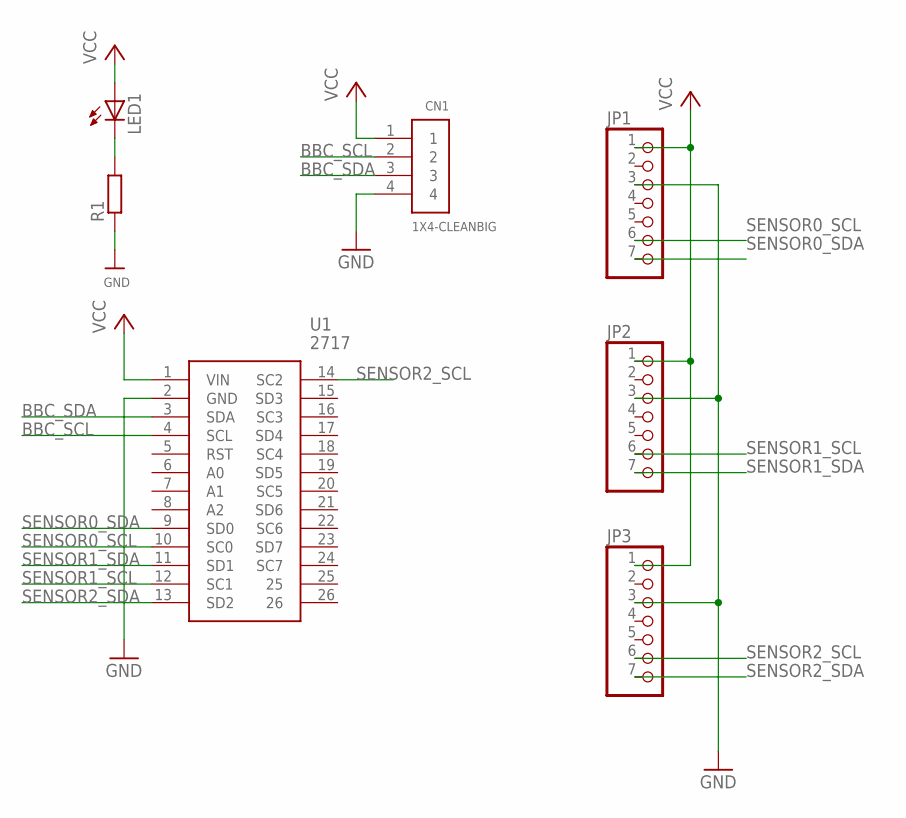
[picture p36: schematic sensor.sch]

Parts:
CN1: 1X4-CLEANBIG; 1X04-CLEANBIG
JP1, JP2, JP3: MICROBUILDER_HEADER-1X7; MICROBUILDER_1X07_OVAL
LED1: LED3MM
R1: R-EU_0204/7; 0204/7
U1: 2717

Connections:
BBC_SCL: CN1.2, U1.4 (SCL)
BBC_SDA: CN1.3, U1.3 (SDA)
GND: CN1.4, JP1.3, JP2.3, JP3.3, R1.1, U1.2 (GND)
unnamed: LED1.K (C), R1.2
SENSOR0_SCL: JP1.6, U1.10 (SC0)
SENSOR0_SDA: JP1.7, U1.9 (SD0)
SENSOR1_SCL: JP2.6, U1.12 (SC1)
SENSOR1_SDA: JP2.7, U1.11 (SD1)
SENSOR2_SCL: JP3.6, U1.14 (SC2)
SENSOR2_SDA: JP3.7, U1.13 (SD2)
VCC: CN1.1, JP1.1, JP2.1, JP3.1, LED1.A, U1.1 (VIN)

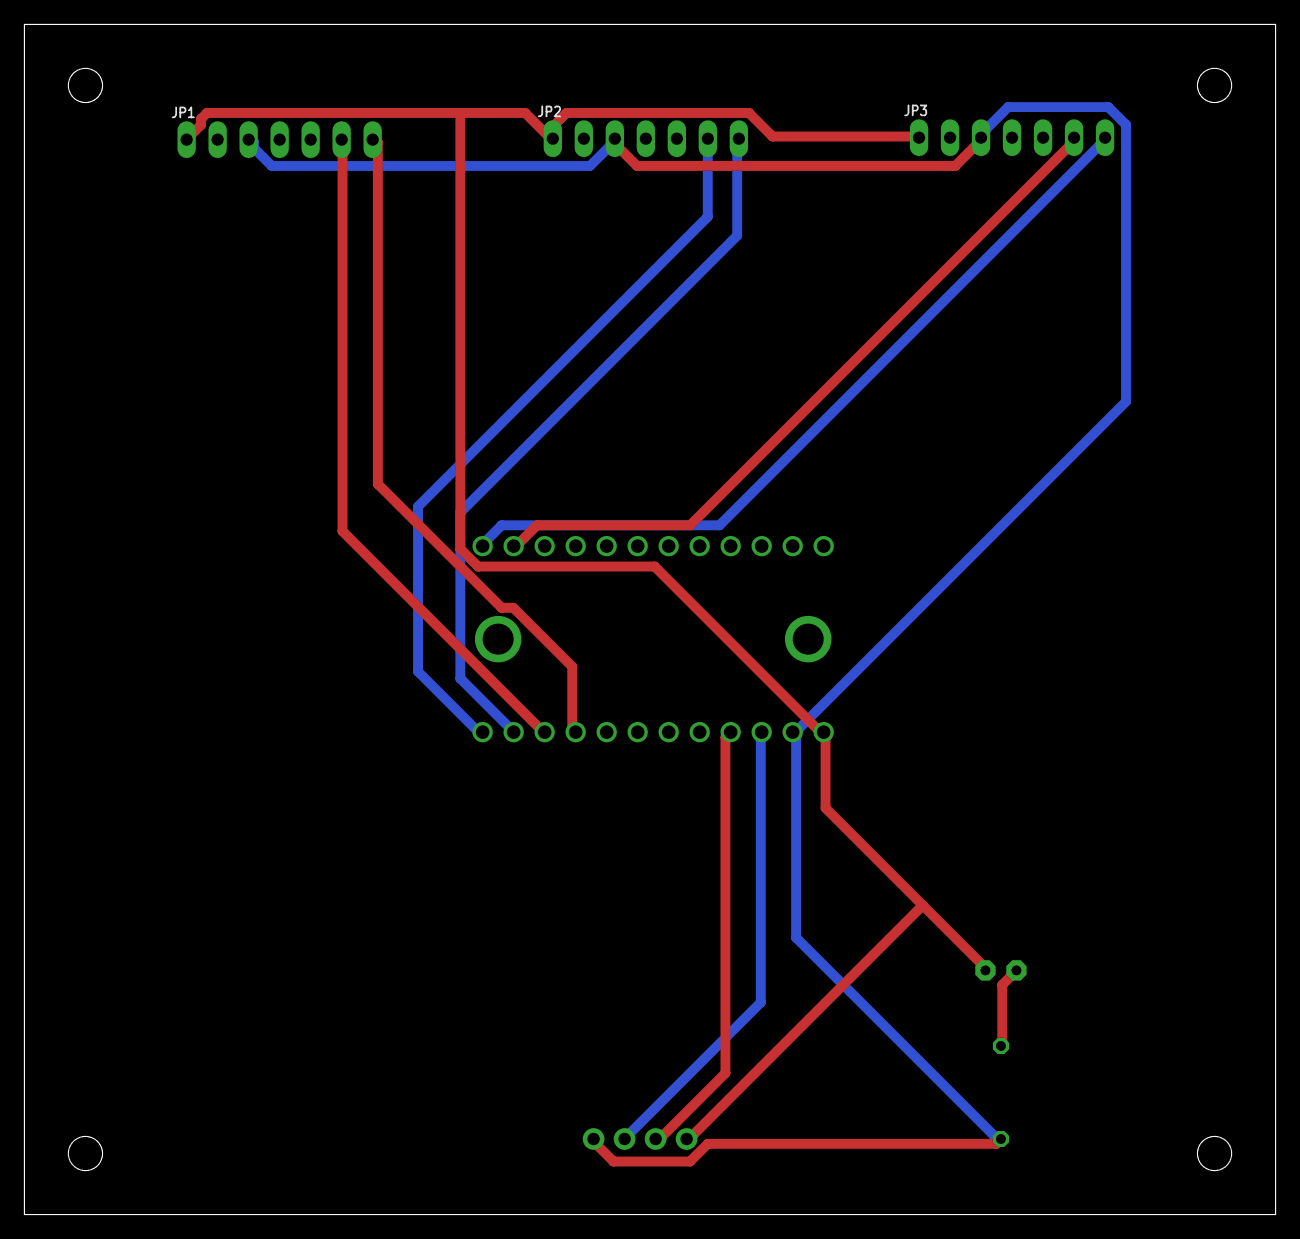
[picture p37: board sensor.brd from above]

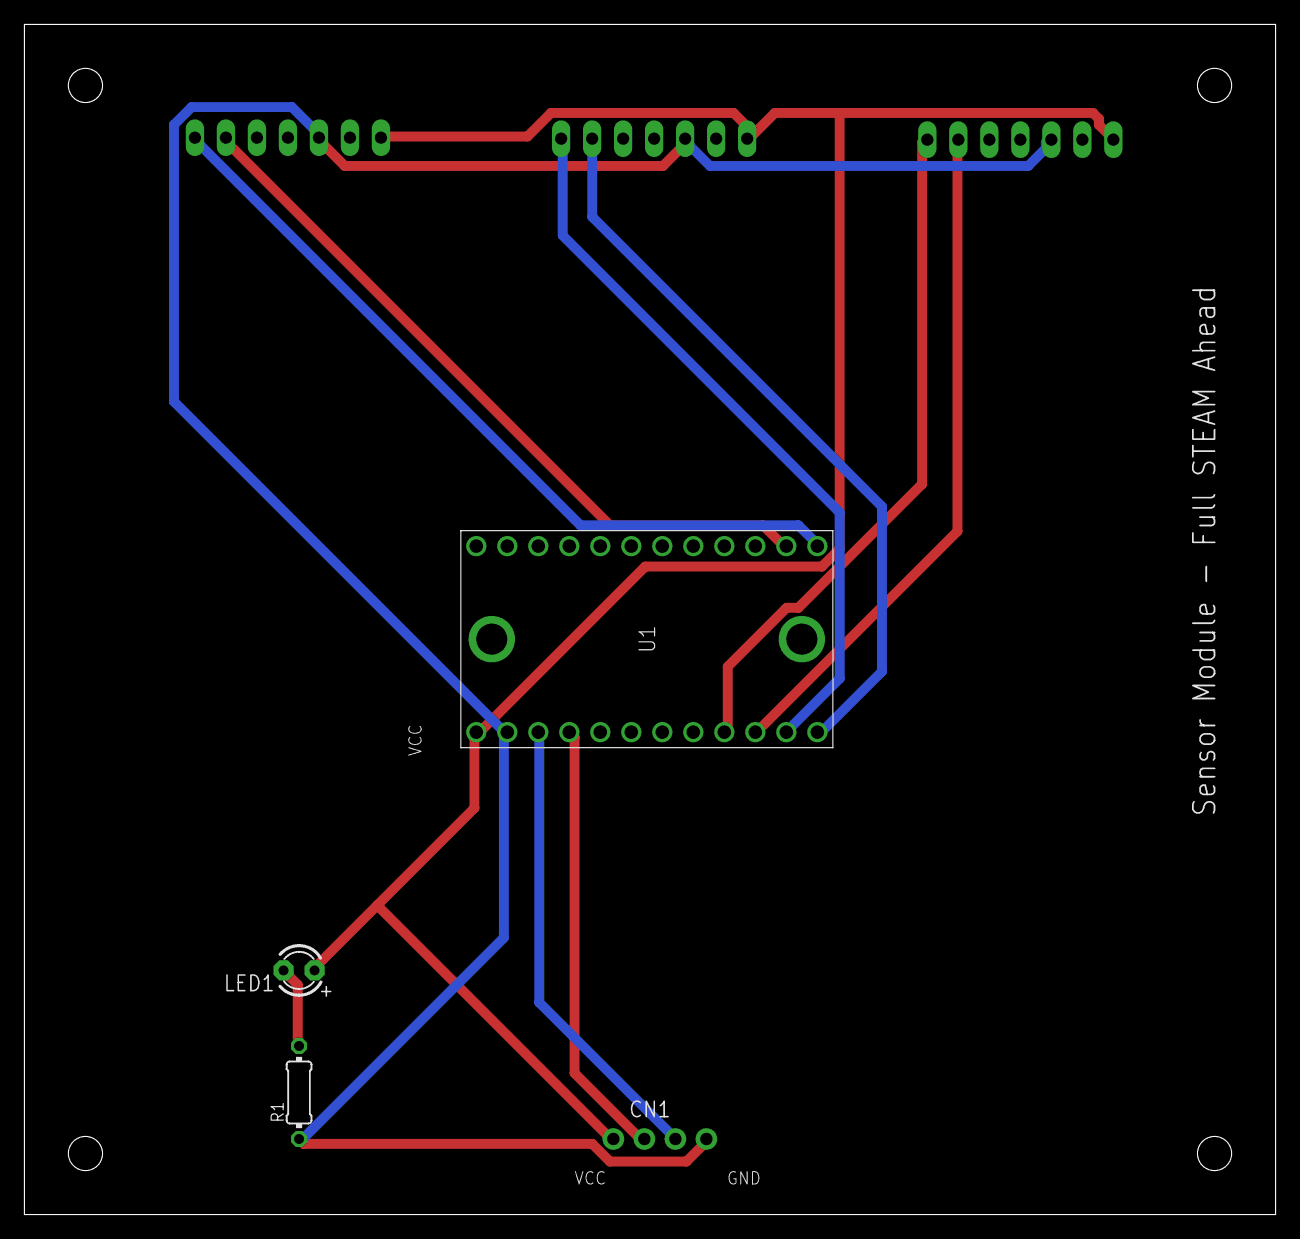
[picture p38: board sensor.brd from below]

Board: 2 copper layers, 102.5 x 97.5 mm, 7 parts (4 on the bottom side), 11 nets.

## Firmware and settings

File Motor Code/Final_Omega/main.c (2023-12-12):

#include <driverlib.h>
#include <msp.h>
#include <stdio.h>
#include <stdbool.h>

int i = 0;  // Time delay variable
int Button1 = 0; // Buttons
int Button2 = 0;
int Button3 = 0;
int Button4 = 0;
int Button1H = 0; // ButtonHistory
int Button2H = 0;
int Button3H = 0;
int Button4H = 0;
int LED1 = 0; // LEDs
int LED2ColorR = 0;
int LED2ColorG = 0;
int LED2ColorB = 0;

#define SLAVE_ADDRESS 0x48  // Default 7-bit slave address is 0x48 according to TypeScript.
#define CONFIG_REG 0x00     // Location of configuration register on TC74A0 temperature sensor (See spec sheet)

volatile unsigned int result = 0;  // Variable for ADC result storages
volatile int PWM = -0;             // Start with a duty cycle of 0.0 %
int TimerDriveCheck = 0;              // Check to prevent errors
int TimerLeftCheck = 0;              // Check to prevent errors
int TimerRightCheck = 0;

// Configure Timer A for UpMode operation
const Timer_A_UpModeConfig upConfig_0 =
{    TIMER_A_CLOCKSOURCE_SMCLK,
     TIMER_A_CLOCKSOURCE_DIVIDER_1,
     60000, // This PWM period, assuming a CPU clock rate of 3 MHz, is 20 ms
     TIMER_A_TAIE_INTERRUPT_DISABLE,
     TIMER_A_CCIE_CCR0_INTERRUPT_ENABLE,
     TIMER_A_DO_CLEAR
};

// Create I2C configuration structure for Module B1 (P6.4 and P6.5)
volatile uint8_t temp_byte;

// Main Program Loop
void main(void){

   // Halt Watchdog timer
   WDT_A_holdTimer();

   //set LEDs at output pins, may turn them on
   GPIO_setAsOutputPin(GPIO_PORT_P1, GPIO_PIN0);
   GPIO_setAsOutputPin(GPIO_PORT_P2, GPIO_PIN0);
   GPIO_setAsOutputPin(GPIO_PORT_P2, GPIO_PIN1);
   GPIO_setAsOutputPin(GPIO_PORT_P2, GPIO_PIN2);

   // System clock Configuration
   CS_setDCOFrequency(3E+6);     // 1E+6 on I2C, but 3E+6 on the BLDC and Servo
   CS_initClockSignal(CS_SMCLK, CS_DCOCLK_SELECT, CS_CLOCK_DIVIDER_1);

    ///// *** Configure Timer A and its interrupt *** /////
    Timer_A_configureUpMode(TIMER_A0_BASE, &upConfig_0);
    Interrupt_setPriority(INT_TA0_0,0);
    Interrupt_enableInterrupt(INT_TA0_0);
    Timer_A_startCounter(TIMER_A0_BASE, TIMER_A_UP_MODE);

    ///// *** Setup Pin 2.4 and 2.5 as PWM output signal *** /////
    P2->SEL0 |= 0x10 ;         // Set bit 4 of P2SEL0 to enable TA0.1 functionality on P2.4
    P2->SEL1 &= ~0x10 ;        // Clear bit 4 of P2SEL1 to enable TA0.1 functionality on P2.4
    P2->DIR |= 0x10 ;          // Set pin 2.4 as an output pin
    TIMER_A0->CCR[1] = 4500 ;     // Set duty cycle on pin 2.4 to 7.5 % to start, the middle of the servo's motion range
    TIMER_A0->CCTL[1] = TIMER_A_CCTLN_OUTMOD_7   ;    // Macro which is equal to 0x00e0, defined in msp432p4111.h
    P2->SEL0 |= 0x20 ;         // Set bit 5 of P2SEL0 to enable TA0.1 functionality on P2.4
    P2->SEL1 &= ~0x20 ;        // Clear bit 5 of P2SEL1 to enable TA0.1 functionality on P2.4
    P2->DIR |= 0x20 ;          // Set pin 2.5 as an output pin
    TIMER_A0->CCR[2] = 3000 ;     // Set duty cycle on pin 2.4 to 5 % to start, should be lowest duty cycle
    TIMER_A0->CCTL[2] = TIMER_A_CCTLN_OUTMOD_7   ;    // Macro which is equal to 0x00e0, defined in msp432p4111.h

   // Initialize GPIO pins for the B1 I2C module
   GPIO_setAsPeripheralModuleFunctionInputPin(GPIO_PORT_P6, GPIO_PIN4 | GPIO_PIN5, GPIO_PRIMARY_MODULE_FUNCTION);

   // Initialize the B1 Module using the I2C configuration structure
   I2C_initSlave(EUSCI_B1_BASE, SLAVE_ADDRESS, EUSCI_B_I2C_OWN_ADDRESS_OFFSET0,EUSCI_B_I2C_OWN_ADDRESS_ENABLE);
   I2C_setMode(EUSCI_B1_BASE, EUSCI_B_I2C_RECEIVE_MODE);
   I2C_enableModule(EUSCI_B1_BASE);
   //printf("\nI2C configuration completed...\n");
   I2C_enableInterrupt(EUSCI_B1_BASE, EUSCI_B_I2C_RECEIVE_INTERRUPT0); // EUSCI_B_I2C_START_INTERRUPT0 | EUSCI_B_I2C_RECEIVE_INTERRUPT0 | EUSCI_B_I2C_RECEIVE_INTERRUPT1 | EUSCI_B_I2C_RECEIVE_INTERRUPT2 | EUSCI_B_I2C_RECEIVE_INTERRUPT3);
   //printf("Configuration applied...\n");

   // Let's keep reading from this register...
   temp_byte = I2C_slaveGetData(EUSCI_B1_BASE);     // Receive the sensor reading byte from the Slave
   //temp_byte = 0xFF; // DIAGNOSTICS

   // Table of Buttons from I2C interface
   Button1 = (temp_byte & (1 << 0))/1;
   Button2 = (temp_byte & (1 << 1))/2;
   Button3 = (temp_byte & (1 << 2))/4;
   Button4 = (temp_byte & (1 << 3))/8;
   //printf("Byte: %d \n", (int) temp_byte);

   // Print the temperature byte to the CCS console
   //printf("Left: %d, Right: %d, Forward: %d, Backwards: %d \n", (int) Button1, (int) Button2, (int) Button3, (int) Button4);
   button_func();

   // LED Module Code
   LED1 = GPIO_getInputPinValue(GPIO_PORT_P1, GPIO_PIN0);
   LED2ColorR = GPIO_getInputPinValue(GPIO_PORT_P2, GPIO_PIN0);
   LED2ColorG = GPIO_getInputPinValue(GPIO_PORT_P2, GPIO_PIN1);
   LED2ColorB = GPIO_getInputPinValue(GPIO_PORT_P2, GPIO_PIN2);

   // Enable all interrupts
   Interrupt_enableMaster();

   while(1){
       for(i=0;i<10000;i++){}
       readControls();
   }
}


// The Interrupt Service Routine (ISR) for Timer A
void readControls(void)
{
    // Receive a temperature sensor data byte
    I2C_setMode(EUSCI_B1_BASE, EUSCI_B_I2C_RECEIVE_MODE);       // Set the I2C module to RECEIVE mode
    temp_byte = I2C_slaveGetData(EUSCI_B1_BASE);     // Receive the sensor reading byte from the Slave

    // Table of Buttons from I2C interface
    Button1 = (temp_byte & (1 << 0))/1;
    Button2 = (temp_byte & (1 << 1))/2;
    Button3 = (temp_byte & (1 << 2))/4;
    Button4 = (temp_byte & (1 << 3))/8;
    //printf("Byte: %d \n", (int) temp_byte);

    // Print the temperature byte to the CCS console
    //printf("Left: %d, Right: %d, Forward: %d, Backwards: %d \n", (int) Button1, (int) Button2, (int) Button3, (int) Button4);
    button_func();
}

// TRY TO MAKE A PROGRAM THAT LINKS EACH BUTTON TO AN LED ON THE MSP. THAT WILL BE I2C
// This needs more code.
void button_func(void)
{
    if (Button1H == Button1){  /// BUTTON 1
        if (Button1 == 0){
        } else if (Button1 == 1){
        }
    }
    else if (Button1H != Button1){
        if (Button1 == 0){
            GPIO_setOutputLowOnPin(GPIO_PORT_P1, GPIO_PIN0); //turn off
            TimerLeftCheck = 0;
            Button1H = 0;
        } else if (Button1 == 1){
            GPIO_setOutputHighOnPin(GPIO_PORT_P1, GPIO_PIN0); //turn on
            TimerLeftCheck = 1;
            Button1H = 1;
        }
    }
    if (Button2H == Button2){   /// BUTTON 2
        if (Button2 == 0){
        } else if (Button2 == 1){
        }
    }
    else if (Button2H != Button2){
        if (Button2 == 0){
            GPIO_setOutputLowOnPin(GPIO_PORT_P2, GPIO_PIN0); //turn off
            TimerRightCheck = 1;
            Button2H = 0;
        } else if (Button2 == 1){
            GPIO_setOutputHighOnPin(GPIO_PORT_P2, GPIO_PIN0); //turn on
            TimerRightCheck = 1;
            Button2H = 1;
        }
    }
    if (Button3H == Button3){   /// BUTTON 3
        if (Button3 == 0){
        } else if (Button3 == 1){
        }
    }
    else if (Button3H != Button3){
        if (Button3 == 0){
            GPIO_setOutputLowOnPin(GPIO_PORT_P2, GPIO_PIN1); //turn off
            TimerDriveCheck = 0;
            Button3H = 0;
        } else if (Button3 == 1){
            GPIO_setOutputHighOnPin(GPIO_PORT_P2, GPIO_PIN1); //turn on
            TimerDriveCheck = 1;
            Button3H = 1;
        }
    }
    if (Button4H == Button4){   /// BUTTON 4
        if (Button4 == 0){
        } else if (Button4 == 1){
        }
    }
    else if (Button4H != Button4){
        if (Button4 == 0){
            GPIO_setOutputLowOnPin(GPIO_PORT_P2, GPIO_PIN2); //turn off
            Button1H = 0;
        } else if (Button4 == 1){
            GPIO_setOutputHighOnPin(GPIO_PORT_P2, GPIO_PIN2); //turn on
            Button4H = 1;
        }
    }
}

//////////////// *** Timer A Interrupt Service Routine *** ///////////////////
void TA0_0_IRQHandler(void){
    if(TimerDriveCheck == 0){
        // Scale the ADC value to lie between 3000 and 3600, corresponding to 5% and 6% duty cycle for
        // our PWM signal, which had a 60000-count period
        PWM = 3000; // 5%
        TIMER_A0->CCR[2] = PWM;
        //printf("PWM Value A: %i \r\n\n",PWM) ;
        }
    else if(TimerDriveCheck == 1){
        PWM = 3600; // 6% of duty cycle
        TIMER_A0->CCR[2] = PWM;
        //printf("PWM ValueA: %i \r\n\n",PWM) ;
        }
    if (TimerLeftCheck == 1){
        // Scale the ADC value to lie between 3000 and 6000, corresponding to 5% and 10% duty cycle for
        // our PWM signal, which had a 60000-count period
        PWM = 3000; // 5%
        TIMER_A0->CCR[1] = PWM;
        //printf("PWM Value B: %i \r\n\n", PWM) ;
        }
    else if (TimerRightCheck == 1){
        PWM = 6000; // 10%
        TIMER_A0->CCR[1] = PWM;
        //printf("PWM Value B: %i \r\n\n", PWM);
        }
    else if(TimerLeftCheck == 0 && TimerRightCheck == 0){
        PWM = 4500; // 7.5%
        TIMER_A0->CCR[1] = PWM;
        //printf("PWM Value: %i \r\n\n", PWM);
    }
    // Clear Timer A Interrupt Flag
    Timer_A_clearCaptureCompareInterrupt(TIMER_A0_BASE, TIMER_A_CAPTURECOMPARE_REGISTER_0);
}

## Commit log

2023-09-25 created base class: - microBit created extensions of microBit: - mainBody - appendageParent created children of appendageParent: - karaokeAppendage - displayAppendage - wheelAppendage - musicBlockApp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
    - allows for coding on vscode locally
    - also compiles locally
    mainBody:
    - has logic to determine which module is connected where
    - has logic to send/receive serially via RX/TX lines
    appendageParent
    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
2023-09-25 created base class: - microBit created extensions of microBit: - mainBody - appendageParent created children of appendageParent: - karaokeAppendage - displayAppendage - wheelAppendage - musicBlockApp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
    - can assign an appendageID to write to output pin
    childAppendage:
    - writes analog signal constantly telling main-body what appendage it is
    - needs code for what each appendage will do
    added software diagram to README
    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
2023-09-28 Changed connections from naive solution to I2C
    Created 'real' block functions with documentation
2023-10-24 removed custom, created file for each module
    added more useful notes to readme
    [pyvenv.cfg]
2023-11-17 removed karaoke module, added button io module
2023-12-12 Addition of Motor CAD and code to repository
    [Axle Front (X2).stl, Center Joint (X4).stl, Differential-full.3mf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]

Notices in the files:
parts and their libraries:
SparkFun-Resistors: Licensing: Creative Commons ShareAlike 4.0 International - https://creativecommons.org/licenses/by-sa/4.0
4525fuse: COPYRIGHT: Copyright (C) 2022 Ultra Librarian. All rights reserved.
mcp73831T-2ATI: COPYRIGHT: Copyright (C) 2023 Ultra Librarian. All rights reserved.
